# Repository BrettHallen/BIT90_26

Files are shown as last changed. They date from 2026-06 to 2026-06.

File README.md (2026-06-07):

# BIT90/26
An attempted recreation of the BIT90 computer released by Bit Corporation (普澤有限公司) in 1983 that is about [US$90,000 (AU$125,000) cheaper than a used one](https://web.archive.org/web/20260206154213/https://www.ebay.com/itm/127471879150):<br>
- Z80 CPU
- TMS9929A VDP
- 2KB RAM (one TC5517/4016 SRAM) expandable to 32KB (expansion cartridge)
- 16KB VRAM (eight 4116 DRAM)
- 24KB ROM (two 2364 + one 2764 or a variation) containing BASIC & Colecovision firmware (?)
- RF & composite video output
- two joystick ports
- Colecovision cartridge/tape compatible (2x15 pin)
- combination audio/video/tape port (DE9)
- expansion edge connector (2x30 pin)
- 5-pin DIN for power (±5V & +12V)

BIT90 original

Heavily relying on all the excellent information shared by [b3rendsh](https://github.com/b3rendsh) in their [BIT90 repository](https://github.com/b3rendsh/bit90).<br>

## [Part 1](/KiCad/BIT90_Original/) - Completed (enough)
The initial aim of the project is to recreate the original schematics in KiCad:<br>
- Sheet 6-1 (Processor): ✅ completed
- Sheet 6-2 (Video Control): ✅ completed
- Sheet 6-3 (Joystick, Audio, Tape): ✅ completed
- Sheet 6-4 (Keyboard): ✅ completed
- Sheet 6-5 (PAL Video Encoder): ❌ lost interest, using a Pico9918 so no point
- Sheet 6-6 (Expansion): ✅ completed
- Sheet 7-5 (PAL Video Encoder/32K): ❌ not needed for recreation
- 32K DRAM (4416x4): 🤔 pending, if I can get the base model working

The Video Encoder schematic isn't really relevant to my proposed re-design so haven't bothered completing them.<br>

Sheet 7-5 and the 32KB DRAM sheets appear to be for an updated system with 32KB of RAM?  This would be the ultimate aim, but let's see if we can get the initial 8KB system working.<br>

## Part 2 - Ongoing
The second part will be to try to create a modern replica as a single board computer.<br>

Ideally:
- integrated keyboard
- upgraded 8KB of RAM
- replace VDP9929A & 16KB DRAM with a [Pico9918](https://github.com/visrealm/pico9918)
- HDMI video output (thanks to the Pico9918)
- replace tri-voltage ±5VDC & 12VDC power requirement with a single 5VDC via USB or 2.1mm socket

The main hurdle would be sourcing the SN76489AN sound generator but I don't think this is ... currently (June 2026) ... too difficult. If you are wary of Chinese sellers, a reliable source of genuine parts is [Unicorn Electronics](https://unicornelectronics.com/IC/GENERATORS.html) in the US.  Grab yourself some EPROMs or exotic CPUs whilst you're there.<br>

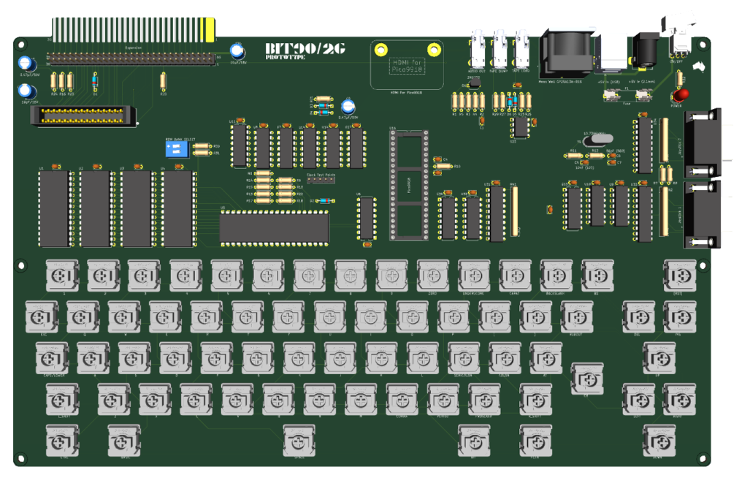
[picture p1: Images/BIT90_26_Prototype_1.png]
Prototype progress


## Keyboard
Recreation of the original keyboard layout.<br>
Designed with [Keyboard Layout Editor](https://www.keyboard-layout-editor.com/) which generates a JOSN file that can be used to generate a template for the key switches with [Plate & Case Builder](http://builder.swillkb.com).<br>

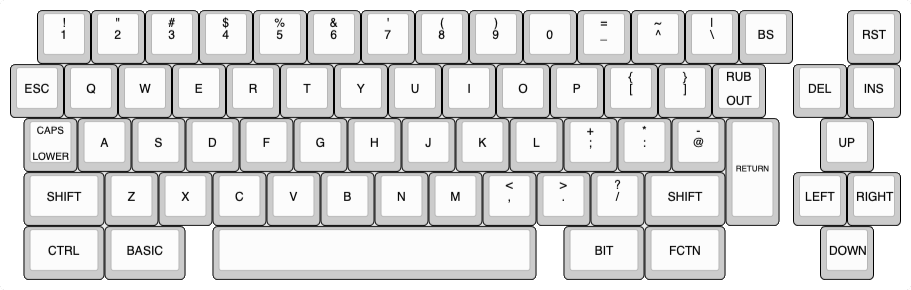
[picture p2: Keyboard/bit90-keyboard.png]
Keyboard layout


## ROMs
The original ROMs (BASIC v3.0) have been dumped and can be found [here](https://forums.atariage.com/topic/296435-bit-90-computer-roms-finally-dumped/).<br>

## BBC Basic
You can now also use a version of BBC Basic on the BIT90 thanks to [b3rendsh's](https://github.com/b3rendsh) work developing [BBX80](https://github.com/b3rendsh/bbx80).<br>

## Status
- 3/JUN/2026: Working on [Part 1](/KiCad/BIT90_Original/)
- 4/JUN/2026: Keyboard layout re-created & template generated
- 5/JUN/2026: Initial redesign [(schematic)](/KiCad/BIT90_26/) completed, error checking/fixing to follow
- 6/JUN/2026: PCB layout started

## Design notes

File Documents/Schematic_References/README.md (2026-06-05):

# Schematic References
Material I used as reference for creating the BIT90 schematics.  Reproduced here in case original links, Google drives, etc. disappear (that never happens, right?).<br>

## BIT90 System
Service manual schematics thanks to [H.J.Berends](https://github.com/b3rendsh/bit90) BIT90 repository.

## ColecoVision Schematic
Thanks to [Dan Boris](https://wiki.console5.com/wiki/Colecovision) on Console5 Wiki.

## ColecoVision KiCad Schematic
Thanks to [ChildOfCv](https://forums.atariage.com/topic/285656-new-colecovision-schematics/) user on AtariAge forums.

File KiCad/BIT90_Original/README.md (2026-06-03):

# BIT90 Original Schematics
Recreated from the [service manual schematics](https://github.com/b3rendsh/bit90/tree/main/docs) with errors corrected, or questioning comments when I couldn't figure it out.<br>

Planning to use these as a basis for a recreated machine - these are not meant to be used for a one-to-one recreation (i.e. not bothering assigning footprints or working on the PCB file) ... but do what you wish with them.<br>

Any errors are either slavishly copied from the original or misinterpreted by me.<br>

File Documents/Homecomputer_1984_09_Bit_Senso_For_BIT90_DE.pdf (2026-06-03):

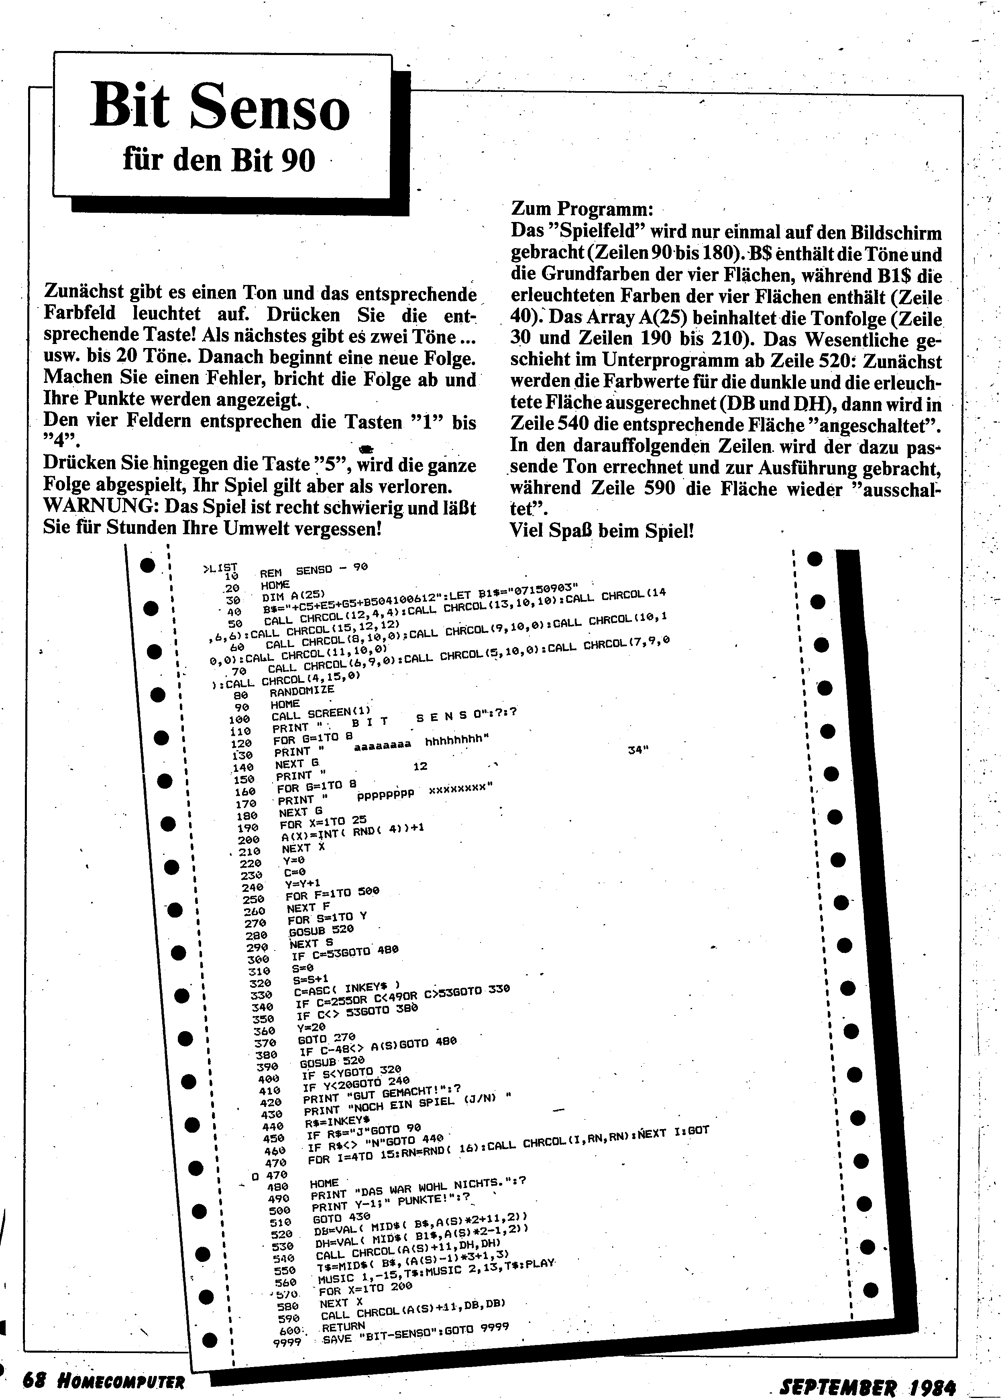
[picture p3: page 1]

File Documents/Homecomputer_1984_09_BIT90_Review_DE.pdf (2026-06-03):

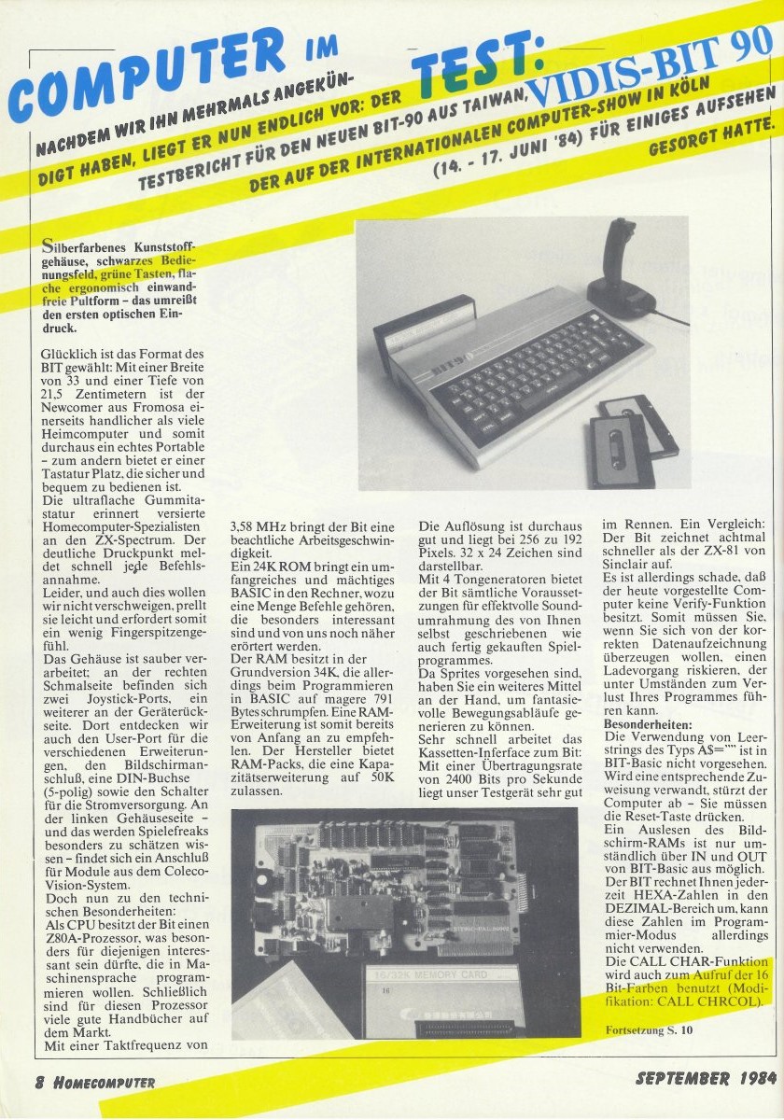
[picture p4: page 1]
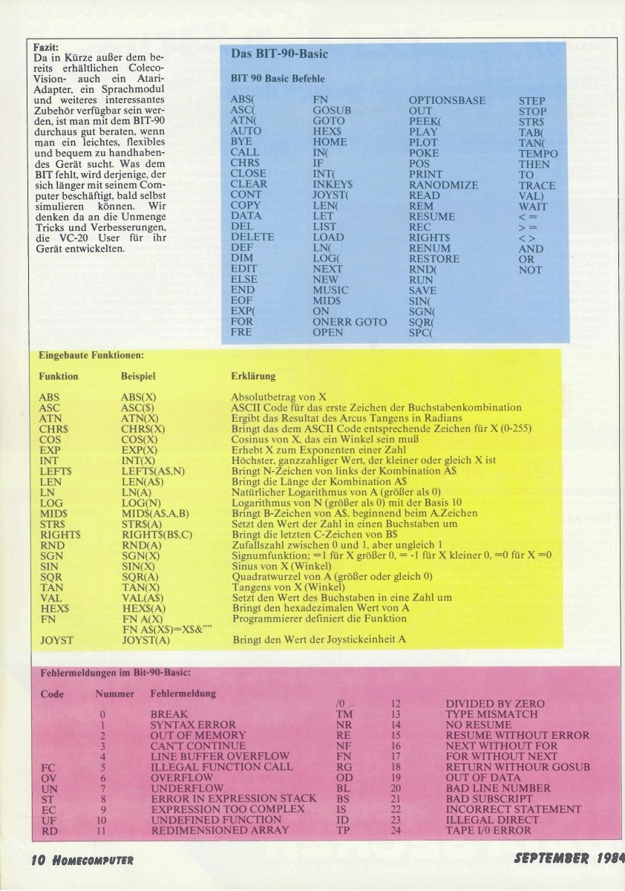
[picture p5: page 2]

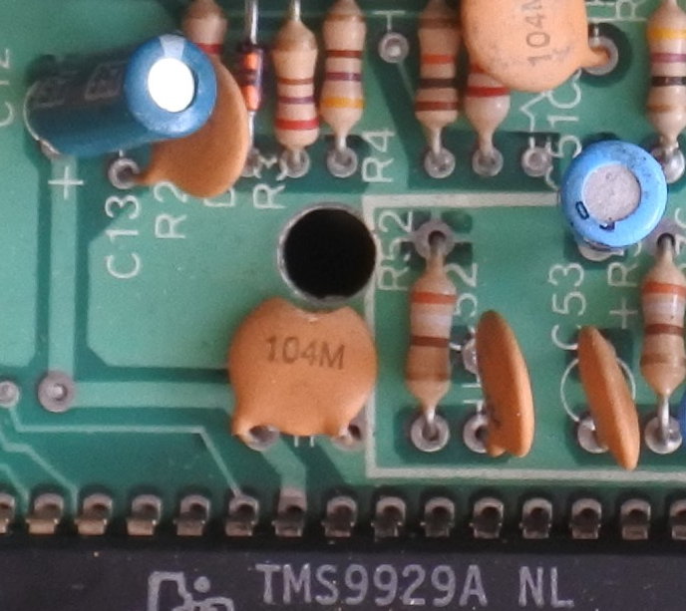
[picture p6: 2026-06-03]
Images/BIT90_motherboard_oopsie.jpg

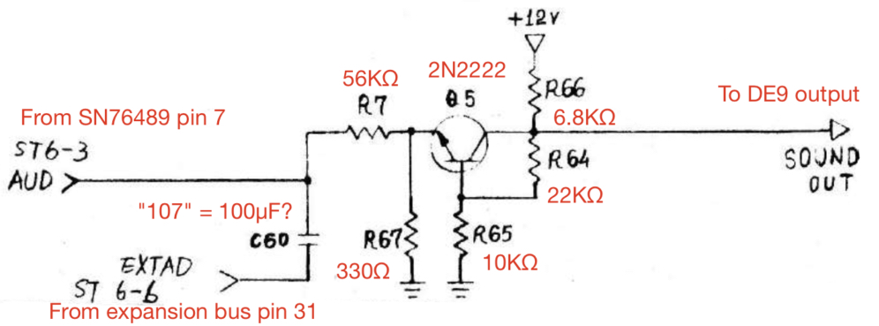
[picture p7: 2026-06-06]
KiCad/BIT90_Scraps/BIT90_sound_output.jpg

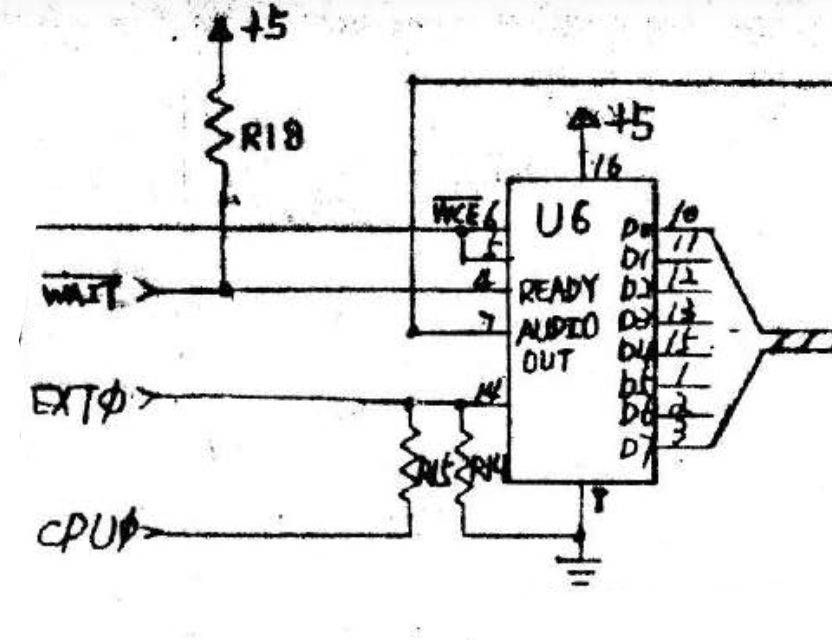
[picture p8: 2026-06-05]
KiCad/BIT90_Scraps/BIT90_Audio_Clocks.jpg

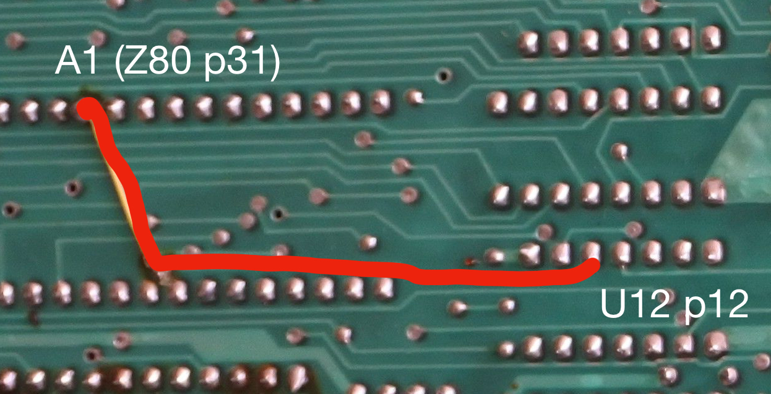
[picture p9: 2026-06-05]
KiCad/BIT90_Scraps/BIT90_scrap1.jpg

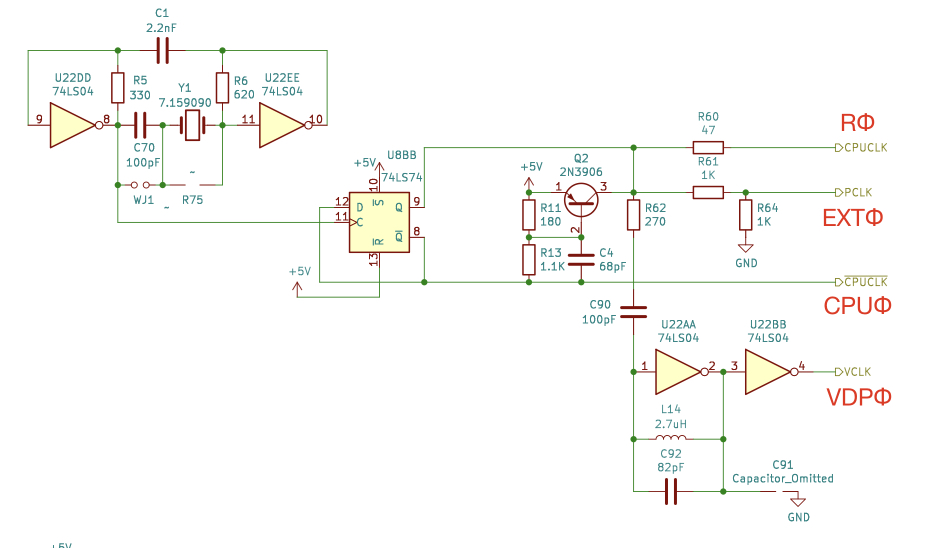
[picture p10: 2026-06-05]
KiCad/BIT90_Scraps/CV_Clocks.jpg

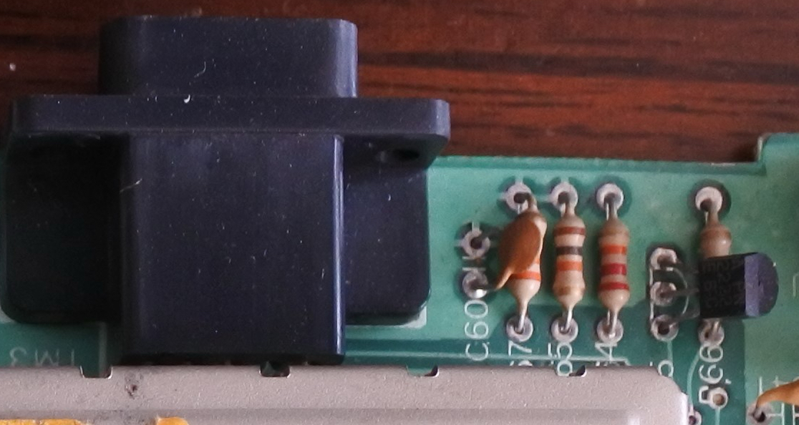
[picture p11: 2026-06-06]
KiCad/BIT90_Scraps/BIT90_sound_output_motherboard.jpg

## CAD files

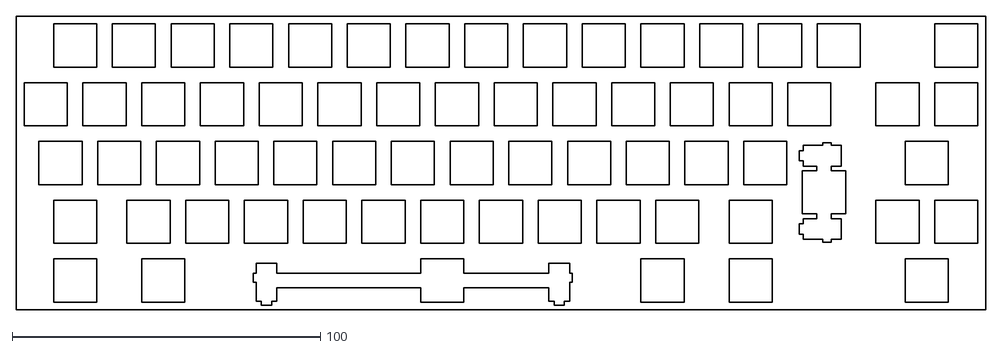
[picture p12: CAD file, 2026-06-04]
Keyboard/bit90-keyboard_switch_template.dxf
314.3 x 95.2

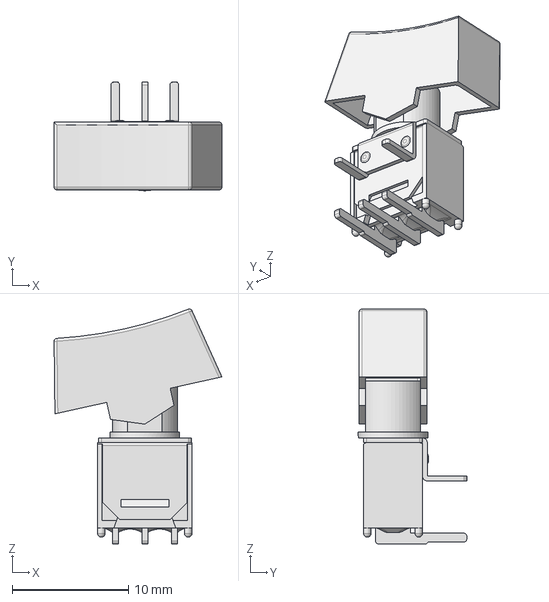
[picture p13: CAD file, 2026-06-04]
KiCad/Symbols/400MSP1R6BLKM6QE/400MSP1R6BLKM6QE.step
14.5 x 9.35 x 20.2 mm

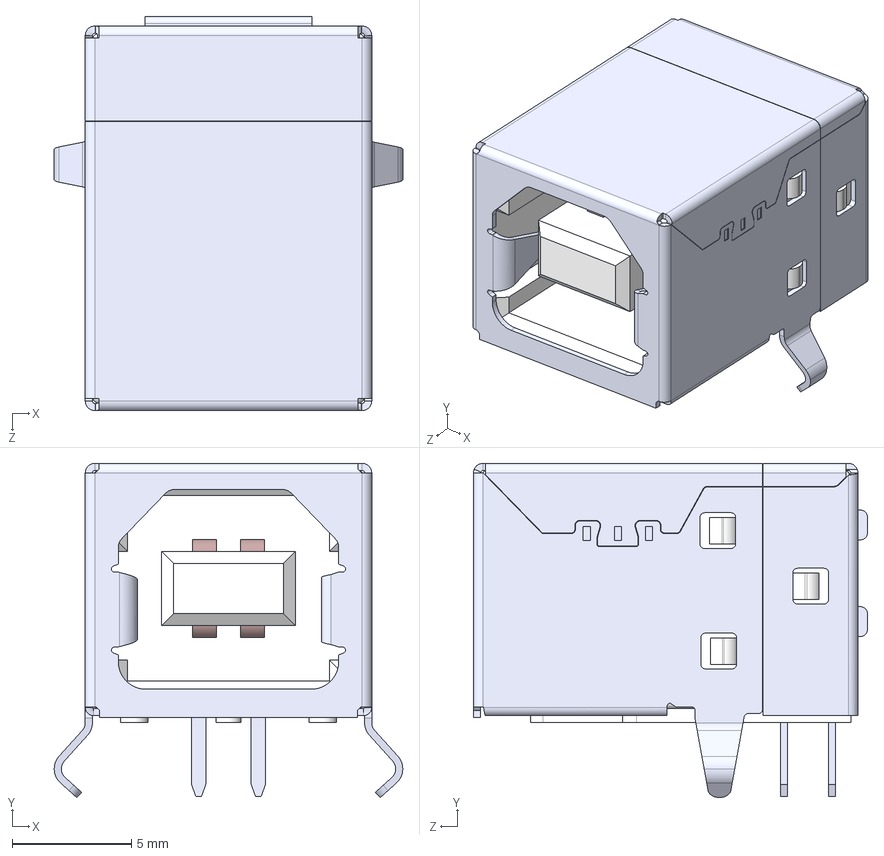
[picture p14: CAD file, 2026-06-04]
KiCad/Symbols/AU_Y1007/AU-Y1007.step
14.6 x 14.0 x 16.5 mm

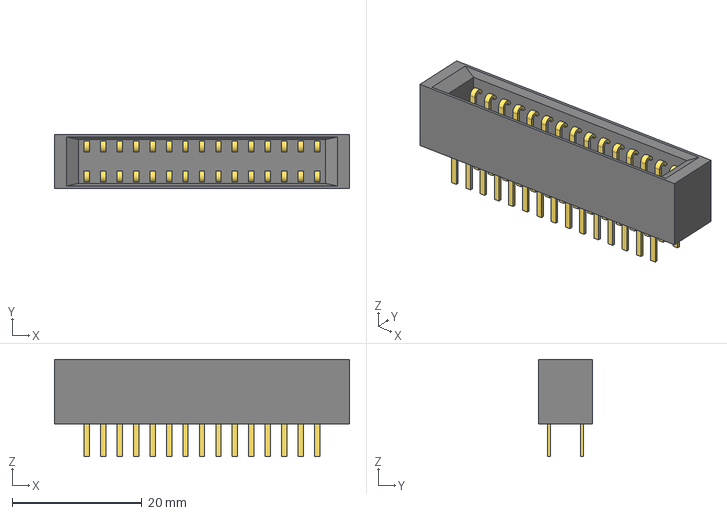
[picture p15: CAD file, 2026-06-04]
KiCad/Symbols/EBC15DRXN/CONN30_2x15_DRXN_SUL.step
45.5 x 8.38 x 15.0 mm

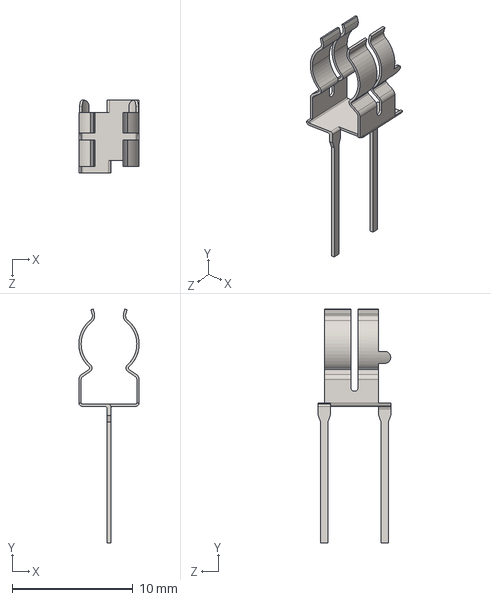
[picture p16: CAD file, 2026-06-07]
KiCad/Symbols/51900001009.stp
5.00 x 19.4 x 6.00 mm

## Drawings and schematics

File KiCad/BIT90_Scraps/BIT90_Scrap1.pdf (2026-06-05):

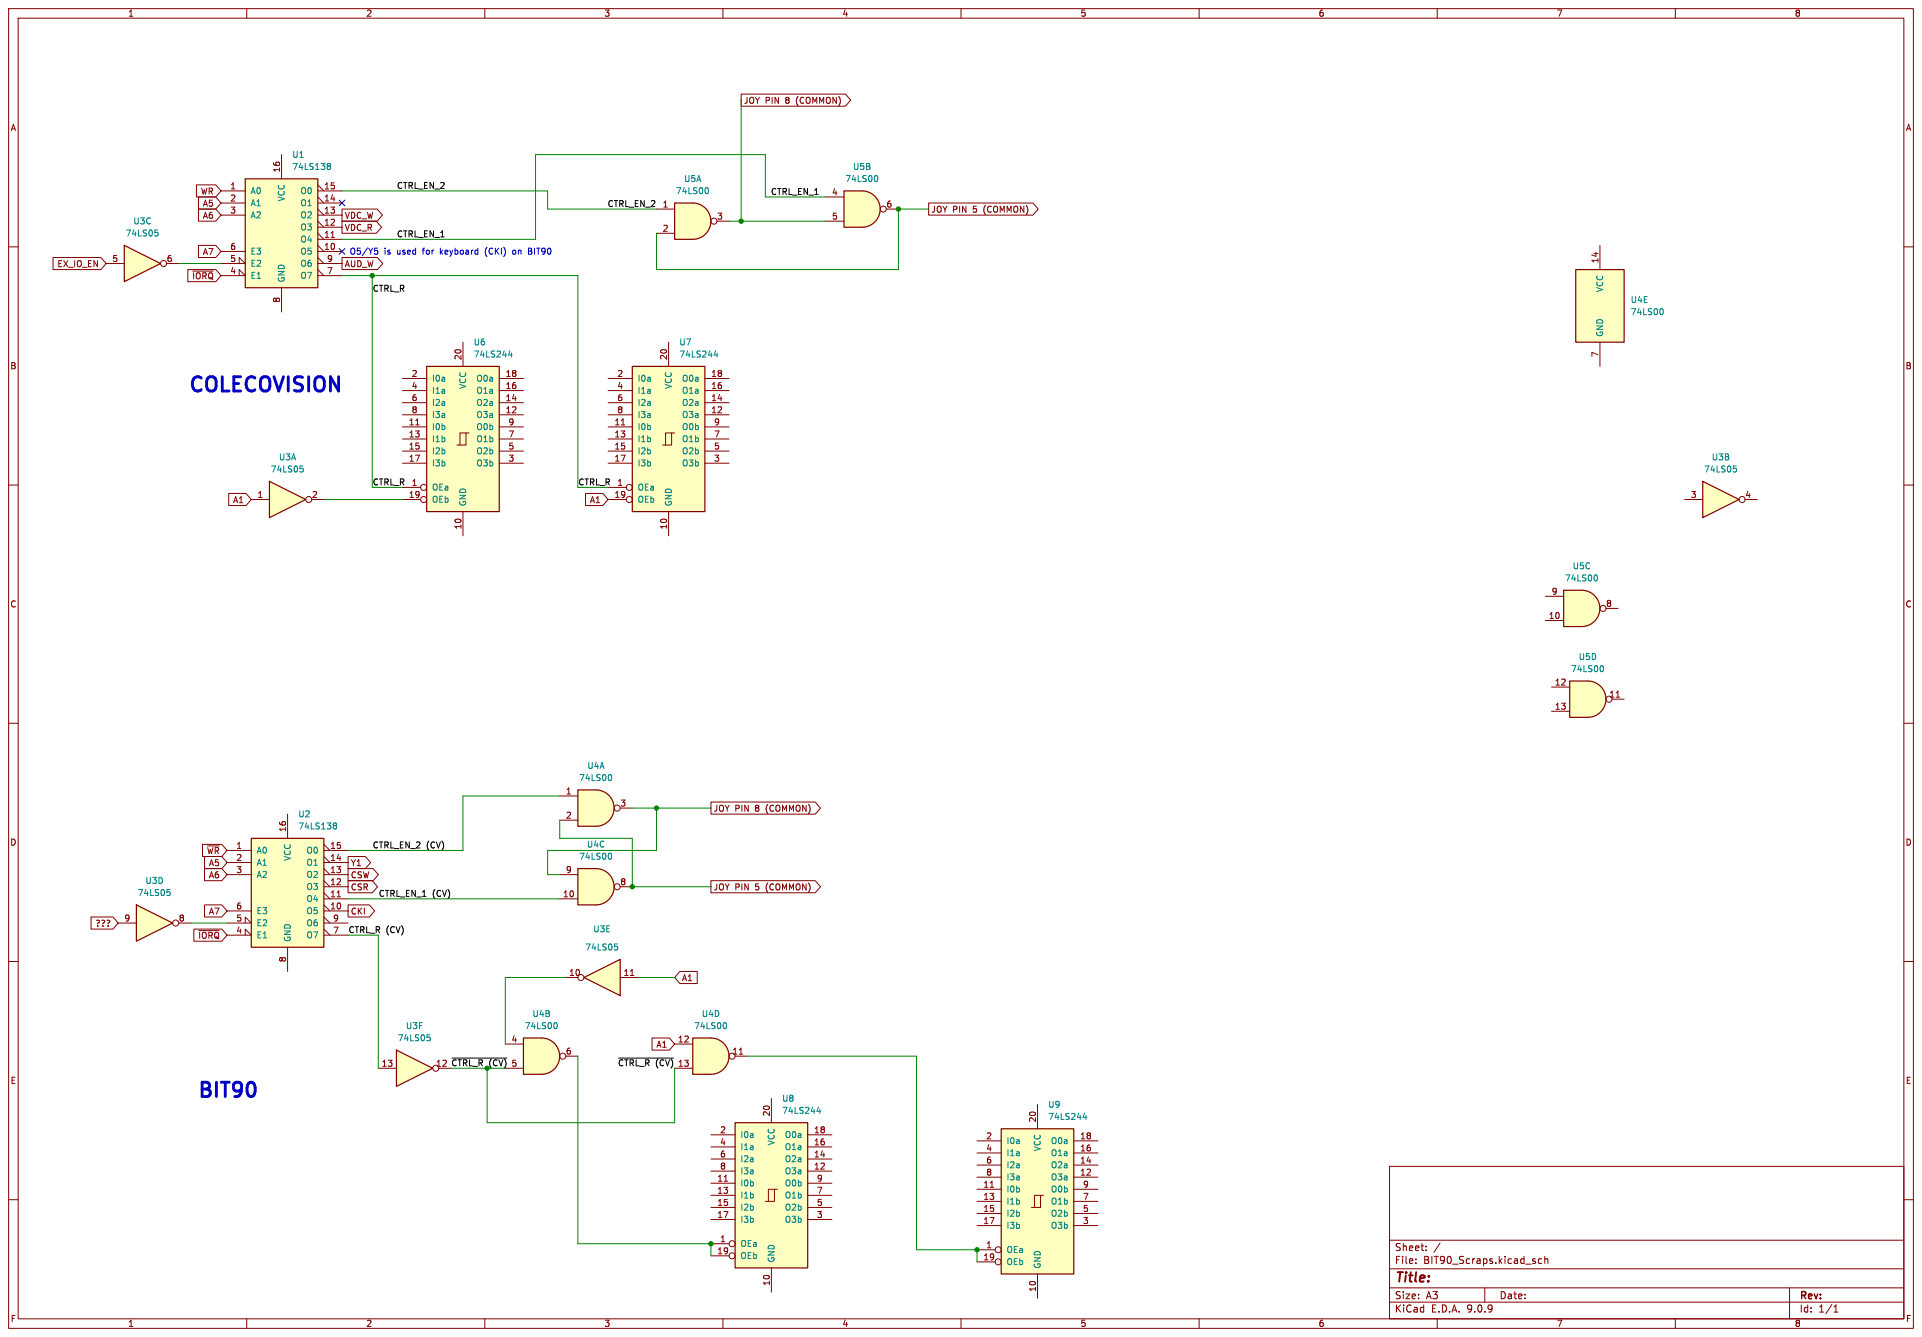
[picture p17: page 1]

O5/Y5 is used for keyboard (CKI) on BIT90 BIT90

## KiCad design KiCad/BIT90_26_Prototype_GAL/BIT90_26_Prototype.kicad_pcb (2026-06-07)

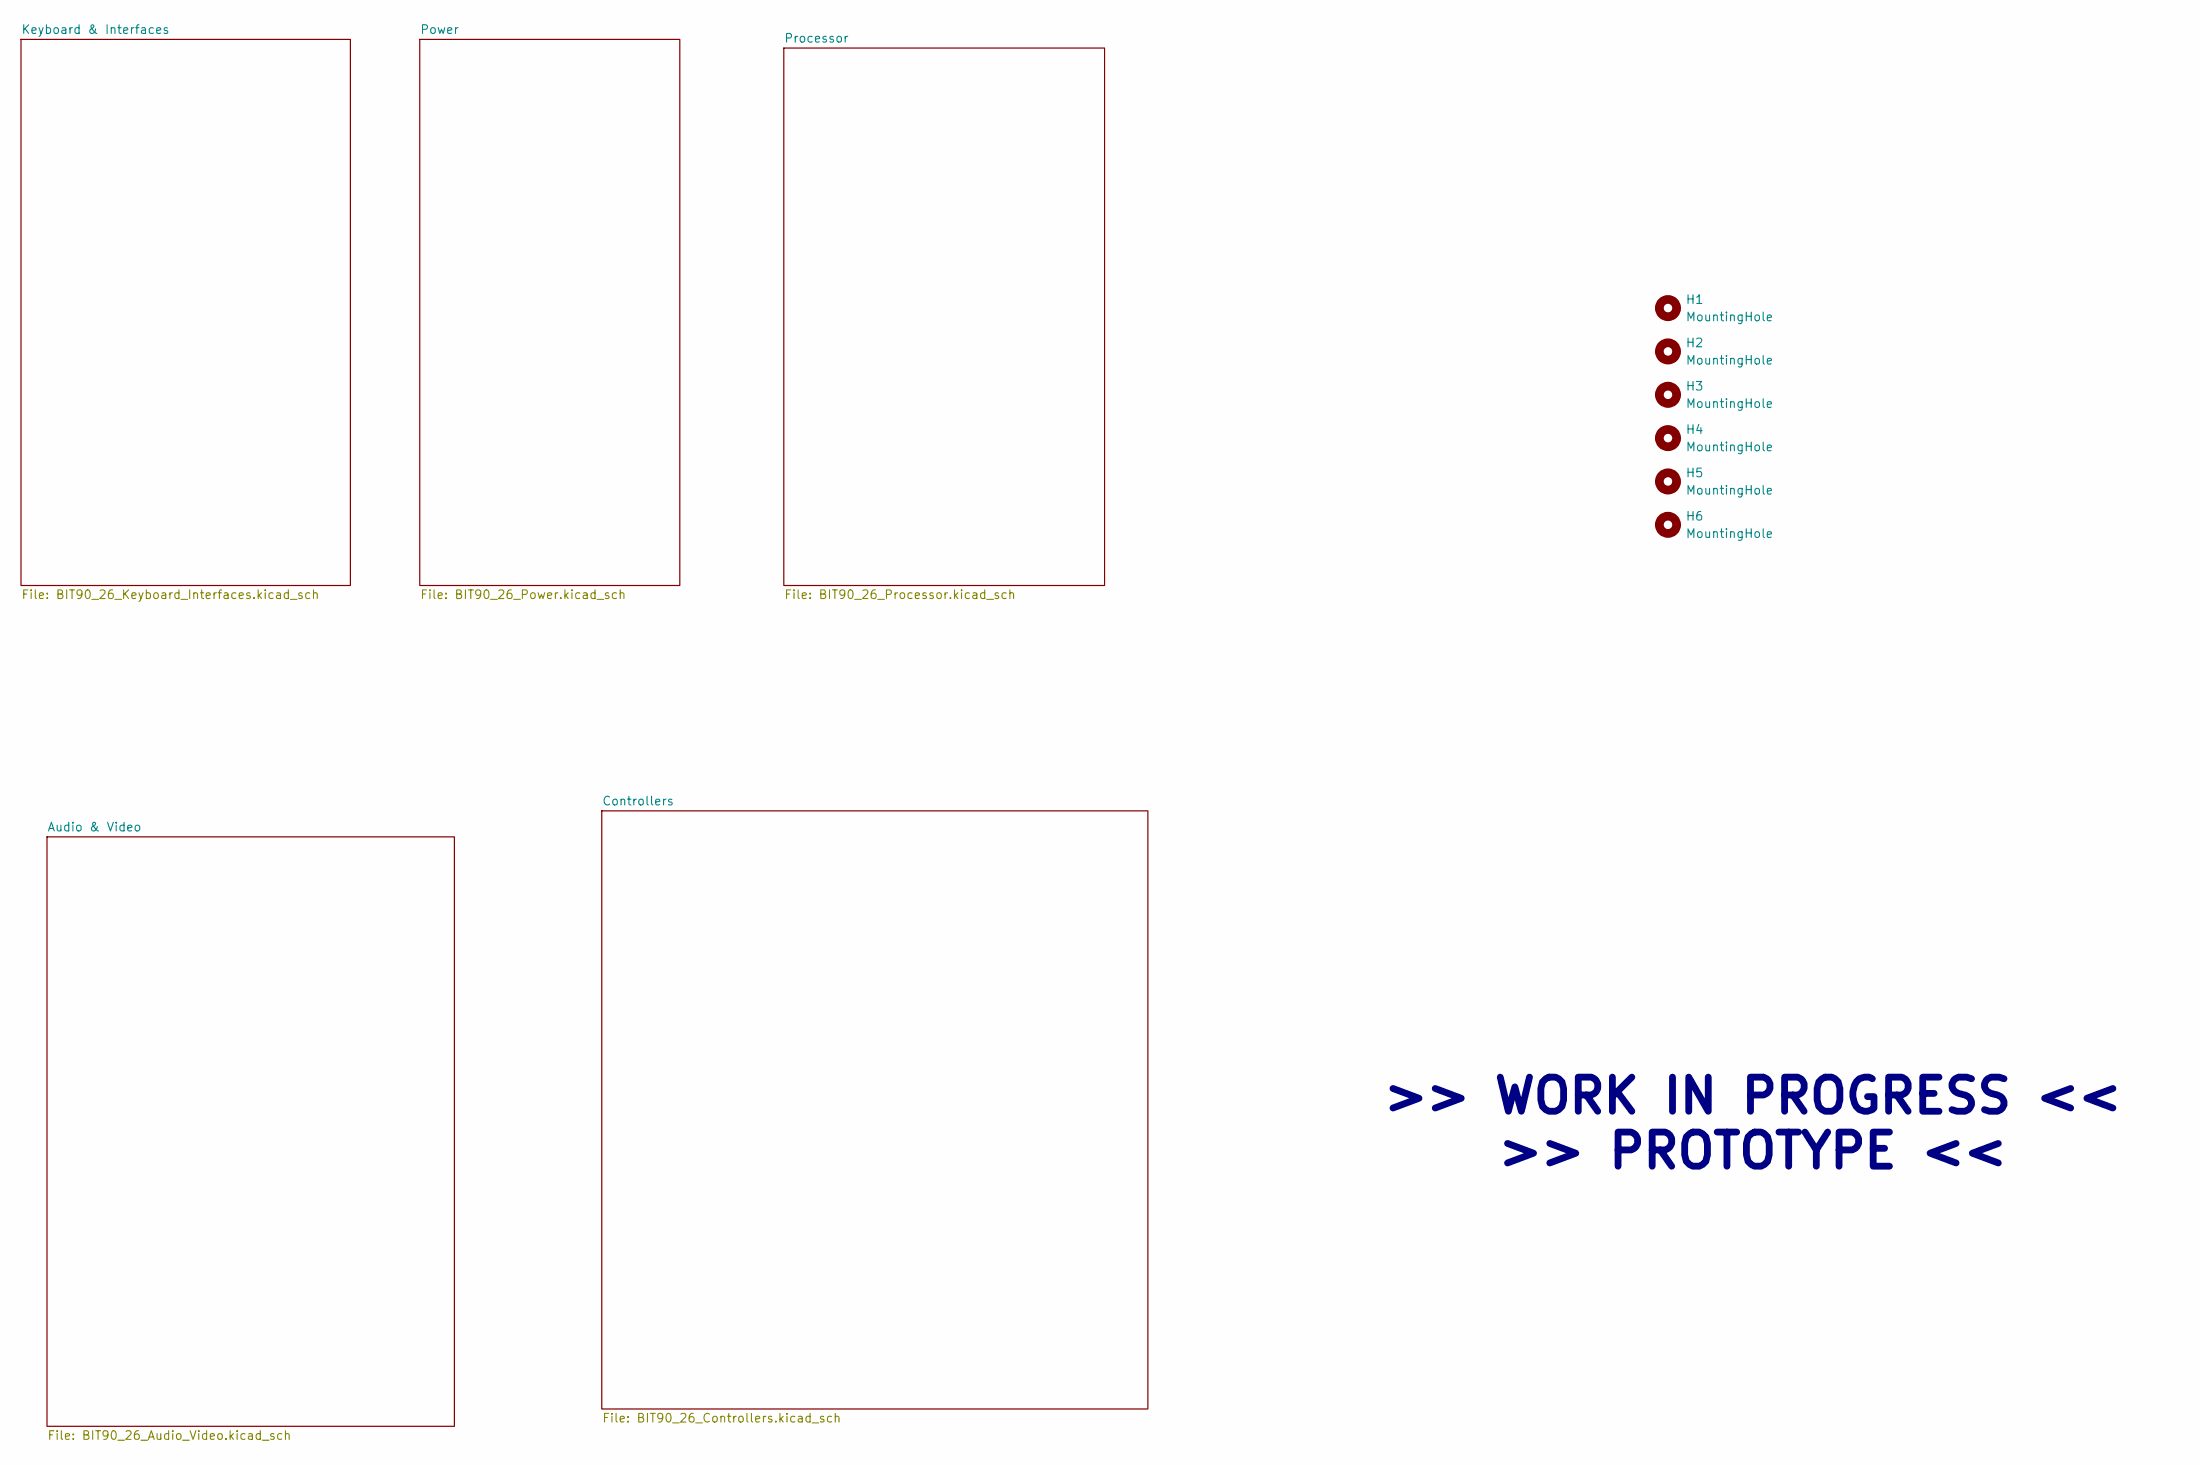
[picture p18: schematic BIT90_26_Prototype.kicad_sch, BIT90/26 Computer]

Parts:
H1, H2, H3, H4, H5, H6: MountingHole; MountingHole_3.2mm_M3

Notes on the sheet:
>> WORK IN PROGRESS << >> PROTOTYPE <<

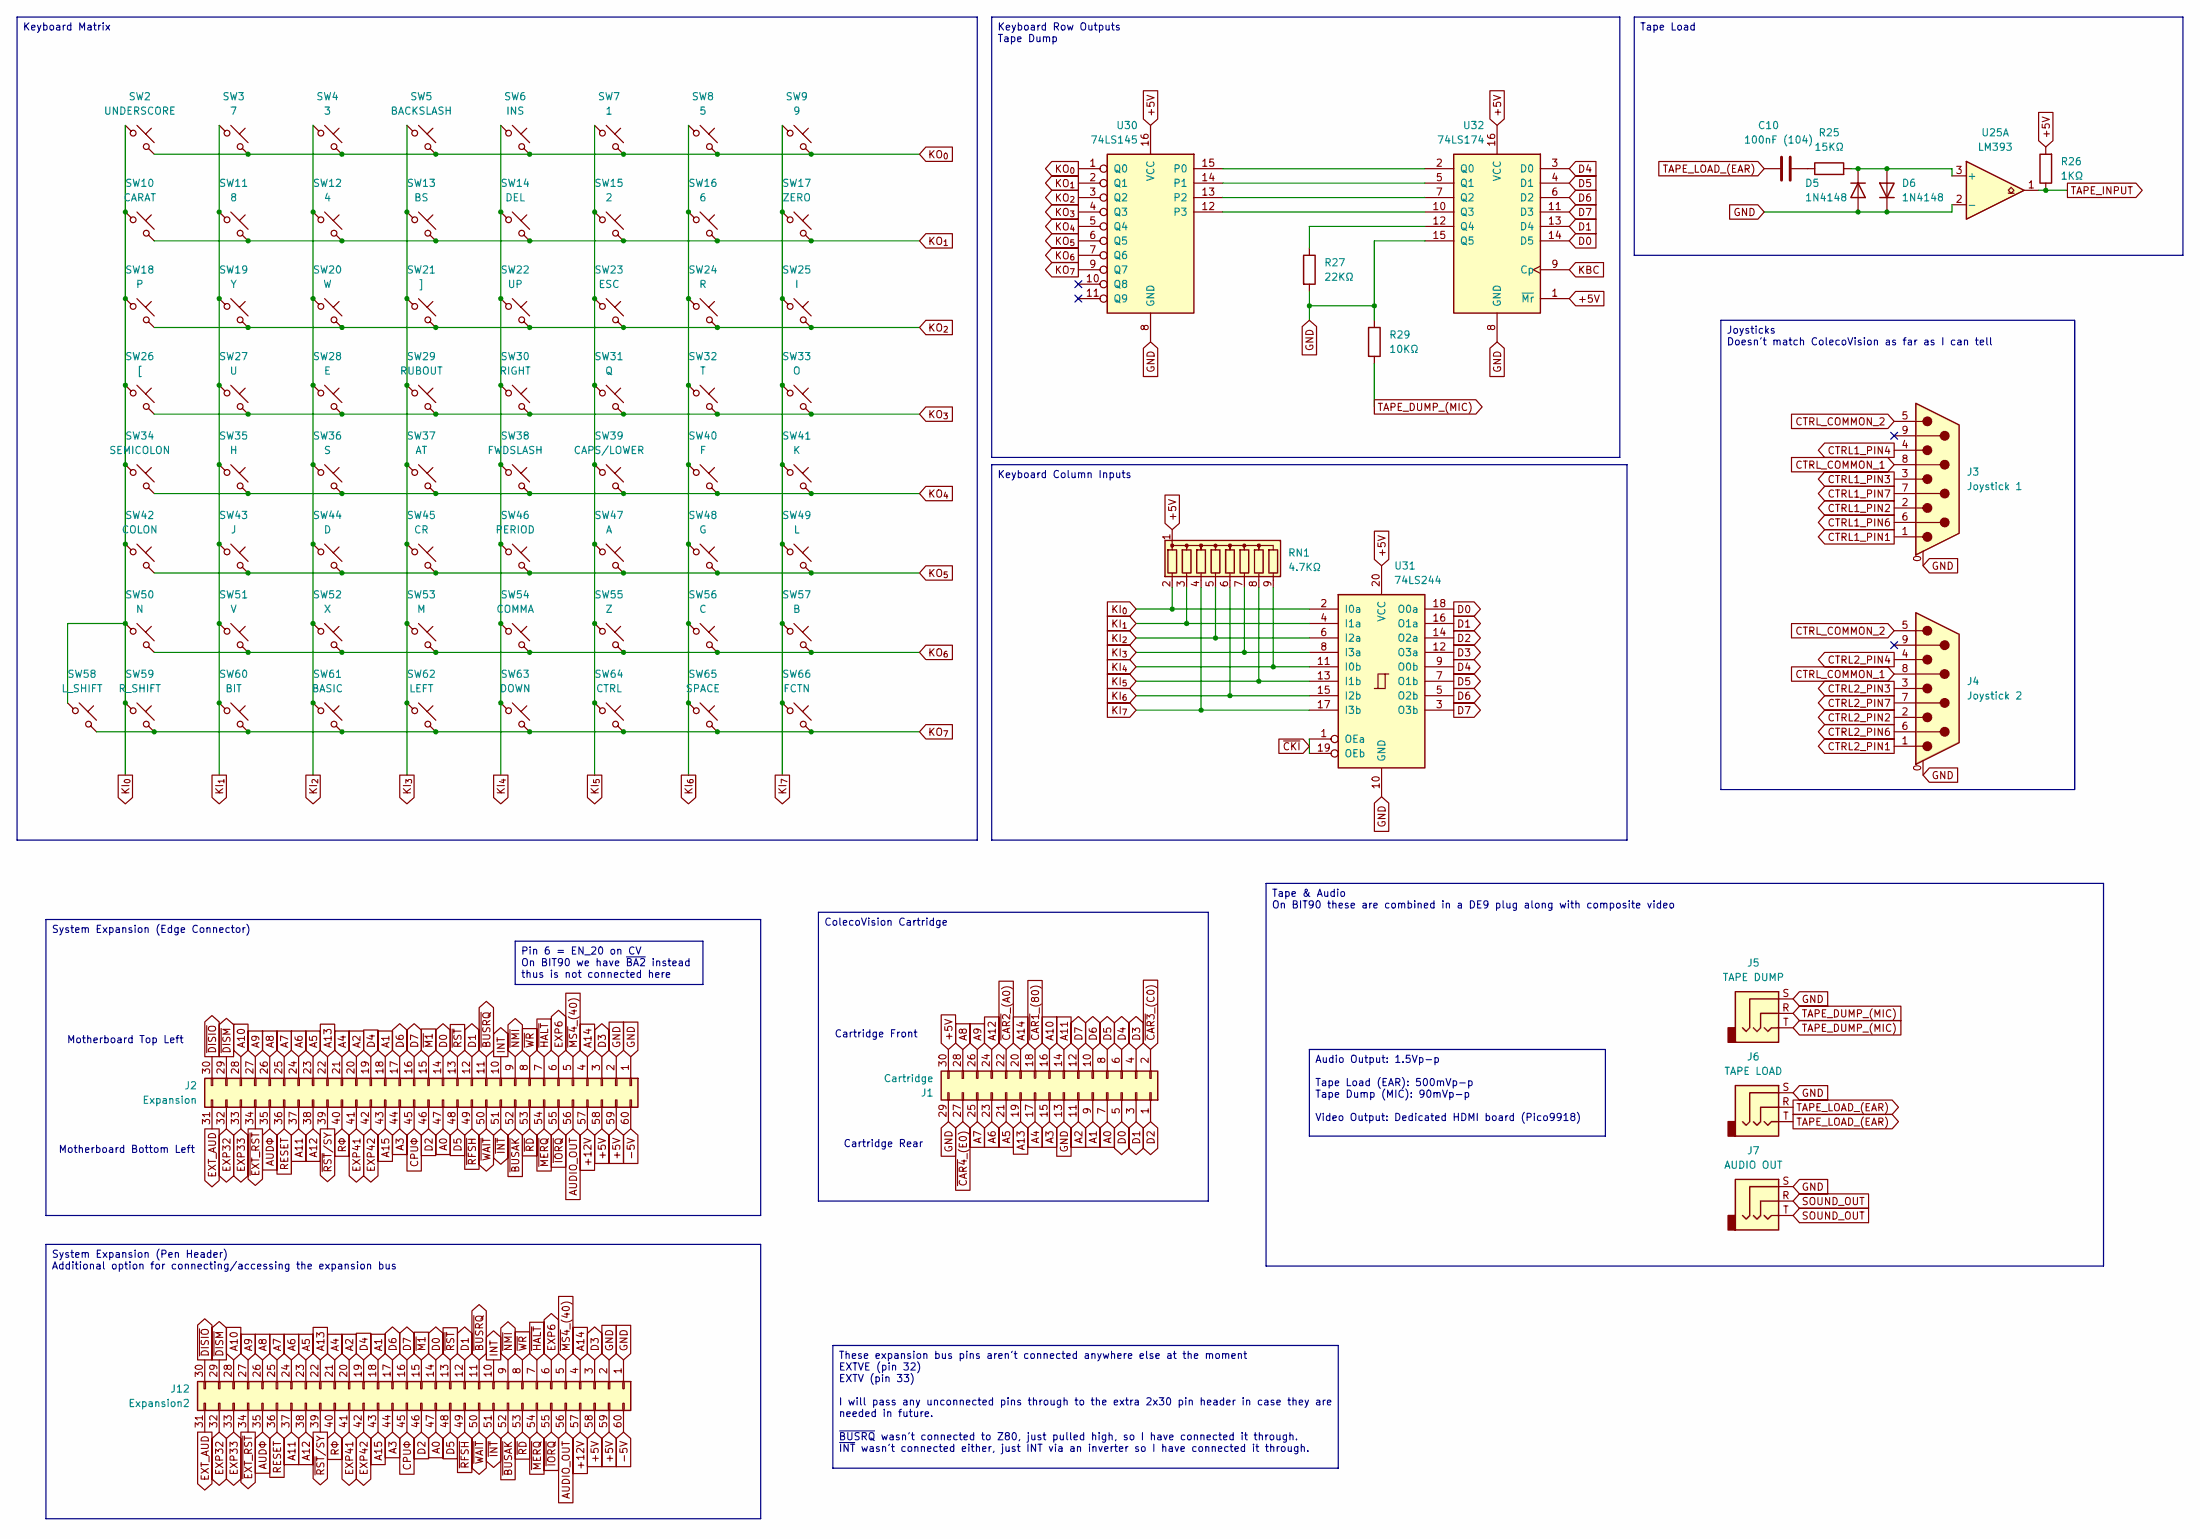
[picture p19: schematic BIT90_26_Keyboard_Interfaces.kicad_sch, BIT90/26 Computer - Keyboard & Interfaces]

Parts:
C10: 100nF (104); C_Disc_D3.4mm_W2.1mm_P2.50mm
D5, D6: 1N4148; D_DO-35_SOD27_P7.62mm_Horizontal
J1: Cartridge; CONN30_2x15_DRXN_SUL
J2: Expansion; BIT90 Expansion
J3: Joystick 1; DSUB-9_Pins_Horizontal_P2.77x2.84mm_EdgePinOffset7.70mm_Hou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
J4: Joystick 2; DSUB-9_Pins_Horizontal_P2.77x2.84mm_EdgePinOffset7.70mm_Hou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
J5: TAPE DUMP; SJ335083ATR
J6: TAPE LOAD; SJ335083ATR
J7: AUDIO OUT; SJ335083ATR
J12: Expansion2; PinHeader_2x30_P2.54mm_Vertical
R25: 15KΩ; R_Axial_DIN0207_L6.3mm_D2.5mm_P7.62mm_Horizontal
R26: 1KΩ; R_Axial_DIN0207_L6.3mm_D2.5mm_P7.62mm_Horizontal
R27: 22KΩ; R_Axial_DIN0207_L6.3mm_D2.5mm_P7.62mm_Horizontal
R29: 10KΩ; R_Axial_DIN0207_L6.3mm_D2.5mm_P7.62mm_Horizontal
RN1: 4.7KΩ; R_Array_SIP9
SW2: UNDERSCORE; SW_Gateron_LowProfile_THT
SW3: 7; SW_Gateron_LowProfile_THT
SW4: 3; SW_Gateron_LowProfile_THT
SW5: BACKSLASH; SW_Gateron_LowProfile_THT
SW6: INS; SW_Gateron_LowProfile_THT
SW7: 1; SW_Gateron_LowProfile_THT
SW8: 5; SW_Gateron_LowProfile_THT
SW9: 9; SW_Gateron_LowProfile_THT
SW10: CARAT; SW_Gateron_LowProfile_THT
SW11: 8; SW_Gateron_LowProfile_THT
SW12: 4; SW_Gateron_LowProfile_THT
SW13: BS; SW_Gateron_LowProfile_THT
SW14: DEL; SW_Gateron_LowProfile_THT
SW15: 2; SW_Gateron_LowProfile_THT
SW16: 6; SW_Gateron_LowProfile_THT
SW17: ZERO; SW_Gateron_LowProfile_THT
SW18: P; SW_Gateron_LowProfile_THT
SW19: Y; SW_Gateron_LowProfile_THT
SW20: W; SW_Gateron_LowProfile_THT
SW21: ]; SW_Gateron_LowProfile_THT
SW22: UP; SW_Gateron_LowProfile_THT
SW23: ESC; SW_Gateron_LowProfile_THT
SW24: R; SW_Gateron_LowProfile_THT
SW25: I; SW_Gateron_LowProfile_THT
SW26: [; SW_Gateron_LowProfile_THT
SW27: U; SW_Gateron_LowProfile_THT
SW28: E; SW_Gateron_LowProfile_THT
SW29: RUBOUT; SW_Gateron_LowProfile_THT
SW30: RIGHT; SW_Gateron_LowProfile_THT
SW31: Q; SW_Gateron_LowProfile_THT
SW32: T; SW_Gateron_LowProfile_THT
SW33: O; SW_Gateron_LowProfile_THT
SW34: SEMICOLON; SW_Gateron_LowProfile_THT
SW35: H; SW_Gateron_LowProfile_THT
SW36: S; SW_Gateron_LowProfile_THT
SW37: AT; SW_Gateron_LowProfile_THT
SW38: FWDSLASH; SW_Gateron_LowProfile_THT
SW39: CAPS/LOWER; SW_Gateron_LowProfile_THT
SW40: F; SW_Gateron_LowProfile_THT
SW41: K; SW_Gateron_LowProfile_THT
SW42: COLON; SW_Gateron_LowProfile_THT
SW43: J; SW_Gateron_LowProfile_THT
SW44: D; SW_Gateron_LowProfile_THT
SW45: CR; SW_Gateron_LowProfile_THT
SW46: PERIOD; SW_Gateron_LowProfile_THT
SW47: A; SW_Gateron_LowProfile_THT
SW48: G; SW_Gateron_LowProfile_THT
SW49: L; SW_Gateron_LowProfile_THT
SW50: N; SW_Gateron_LowProfile_THT
SW51: V; SW_Gateron_LowProfile_THT
SW52: X; SW_Gateron_LowProfile_THT
SW53: M; SW_Gateron_LowProfile_THT
SW54: COMMA; SW_Gateron_LowProfile_THT
SW55: Z; SW_Gateron_LowProfile_THT
SW56: C; SW_Gateron_LowProfile_THT
SW57: B; SW_Gateron_LowProfile_THT
SW58: L_SHIFT; SW_Gateron_LowProfile_THT
SW59: R_SHIFT; SW_Gateron_LowProfile_THT
SW60: BIT; SW_Gateron_LowProfile_THT
SW61: BASIC; SW_Gateron_LowProfile_THT
SW62: LEFT; SW_Gateron_LowProfile_THT
SW63: DOWN; SW_Gateron_LowProfile_THT
SW64: CTRL; SW_Gateron_LowProfile_THT
SW65: SPACE; SW_Gateron_LowProfile_THT
SW66: FCTN; SW_Gateron_LowProfile_THT
U25: LM393; DIP-8_W7.62mm
U30: 74LS145; DIP-16_W7.62mm
U31: 74LS244; DIP-20_W7.62mm
U32: 74LS174; DIP-16_W7.62mm

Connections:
+5V: J1.30, J2.58, J2.59, J12.58, J12.59, R26.2, RN1.1 (common), U30.16 (VCC), U31.20 (VCC), U32.1 (~Mr), U32.16 (VCC); also elsewhere on the board
+12V: J2.57, J12.57; also elsewhere on the board
-5V: J2.60, J12.60; also elsewhere on the board
A0: J1.7, J2.47, J12.47; also elsewhere on the board
A1: J1.9, J2.18, J12.18; also elsewhere on the board
A2: J1.11, J2.20, J12.20; also elsewhere on the board
A3: J1.15, J2.44, J12.44; also elsewhere on the board
A4: J1.17, J2.21, J12.21; also elsewhere on the board
A5: J1.21, J2.23, J12.23; also elsewhere on the board
A6: J1.23, J2.24, J12.24; also elsewhere on the board
A7: J1.25, J2.25, J12.25; also elsewhere on the board
A8: J1.28, J2.26, J12.26; also elsewhere on the board
A9: J1.26, J2.27, J12.27; also elsewhere on the board
A10: J1.16, J2.28, J12.28; also elsewhere on the board
A11: J1.14, J2.37, J12.37; also elsewhere on the board
A12: J1.24, J2.38, J12.38; also elsewhere on the board
A13: J1.19, J2.22, J12.22; also elsewhere on the board
A14: J1.20, J2.4, J12.4; also elsewhere on the board
A15: J2.43, J12.43; also elsewhere on the board
AUDIO_OUT: J2.56, J12.56; also elsewhere on the board
AUDΦ: J2.35, J12.35; also elsewhere on the board
CPUΦ: J2.45, J12.45; also elsewhere on the board
CTRL1_PIN1: J3.1; also elsewhere on the board
CTRL1_PIN2: J3.2; also elsewhere on the board
CTRL1_PIN3: J3.3; also elsewhere on the board
CTRL1_PIN4: J3.4; also elsewhere on the board
CTRL1_PIN6: J3.6; also elsewhere on the board
CTRL1_PIN7: J3.7; also elsewhere on the board
CTRL2_PIN1: J4.1; also elsewhere on the board
CTRL2_PIN2: J4.2; also elsewhere on the board
CTRL2_PIN3: J4.3; also elsewhere on the board
CTRL2_PIN4: J4.4; also elsewhere on the board
CTRL2_PIN6: J4.6; also elsewhere on the board
CTRL2_PIN7: J4.7; also elsewhere on the board
CTRL_COMMON_1: J3.8, J4.8; also elsewhere on the board
CTRL_COMMON_2: J3.5, J4.5; also elsewhere on the board
D0: J1.5, J2.14, J12.14, U31.18 (O0a), U32.14 (D5); also elsewhere on the board
D1: J1.3, J2.12, J12.12, U31.16 (O1a), U32.13 (D4); also elsewhere on the board
D2: J1.1, J2.46, J12.46, U31.14 (O2a); also elsewhere on the board
D3: J1.4, J2.3, J12.3, U31.12 (O3a); also elsewhere on the board
D4: J1.6, J2.19, J12.19, U31.9 (O0b), U32.3 (D0); also elsewhere on the board
D5: J1.8, J2.48, J12.48, U31.7 (O1b), U32.4 (D1); also elsewhere on the board
D6: J1.10, J2.17, J12.17, U31.5 (O2b), U32.6 (D2); also elsewhere on the board
D7: J1.12, J2.16, J12.16, U31.3 (O3b), U32.11 (D3); also elsewhere on the board
EXP6: J2.6, J12.6
EXP32: J2.32, J12.32
EXP33: J2.33, J12.33
EXP41: J2.41, J12.41
EXP42: J2.42, J12.42
EXT_AUD: J2.31, J12.31; also elsewhere on the board
GND: D5.2 (A), D6.1 (K), J1.13, J1.29, J2.1, J2.2, J3.0 (SH), J4.0 (SH), J5.S, J6.S, J7.S, J12.1, J12.2, R27.2, R29.1, U25.2 (-), U30.8 (GND), U31.10 (GND), U32.8 (GND), U32.15 (Q5); also elsewhere on the board
INT: J2.10, J12.10; also elsewhere on the board
KBC: U32.9 (Cp); also elsewhere on the board
KI_{0}: RN1.2 (R1), SW2.1, SW10.1, SW18.1, SW26.1, SW34.1, SW42.1, SW50.1, SW58.1, SW59.1, U31.2 (I0a)
KI_{1}: RN1.3 (R2), SW3.1, SW11.1, SW19.1, SW27.1, SW35.1, SW43.1, SW51.1, SW60.1, U31.4 (I1a)
KI_{2}: RN1.5 (R4), SW4.1, SW12.1, SW20.1, SW28.1, SW36.1, SW44.1, SW52.1, SW61.1, U31.6 (I2a)
KI_{3}: RN1.7 (R6), SW5.1, SW13.1, SW21.1, SW29.1, SW37.1, SW45.1, SW53.1, SW62.1, U31.8 (I3a)
KI_{4}: RN1.9 (R8), SW6.1, SW14.1, SW22.1, SW30.1, SW38.1, SW46.1, SW54.1, SW63.1, U31.11 (I0b)
KI_{5}: RN1.8 (R7), SW7.1, SW15.1, SW23.1, SW31.1, SW39.1, SW47.1, SW55.1, SW64.1, U31.13 (I1b)
KI_{6}: RN1.6 (R5), SW8.1, SW16.1, SW24.1, SW32.1, SW40.1, SW48.1, SW56.1, SW65.1, U31.15 (I2b)
KI_{7}: RN1.4 (R3), SW9.1, SW17.1, SW25.1, SW33.1, SW41.1, SW49.1, SW57.1, SW66.1, U31.17 (I3b)
KO_{0}: SW2.2, SW3.2, SW4.2, SW5.2, SW6.2, SW7.2, SW8.2, SW9.2, U30.1 (Q0)
KO_{1}: SW10.2, SW11.2, SW12.2, SW13.2, SW14.2, SW15.2, SW16.2, SW17.2, U30.2 (Q1)
KO_{2}: SW18.2, SW19.2, SW20.2, SW21.2, SW22.2, SW23.2, SW24.2, SW25.2, U30.3 (Q2)
KO_{3}: SW26.2, SW27.2, SW28.2, SW29.2, SW30.2, SW31.2, SW32.2, SW33.2, U30.4 (Q3)
KO_{4}: SW34.2, SW35.2, SW36.2, SW37.2, SW38.2, SW39.2, SW40.2, SW41.2, U30.5 (Q4)
KO_{5}: SW42.2, SW43.2, SW44.2, SW45.2, SW46.2, SW47.2, SW48.2, SW49.2, U30.6 (Q5)
KO_{6}: SW50.2, SW51.2, SW52.2, SW53.2, SW54.2, SW55.2, SW56.2, SW57.2, U30.7 (Q6)
KO_{7}: SW58.2, SW59.2, SW60.2, SW61.2, SW62.2, SW63.2, SW64.2, SW65.2, SW66.2, U30.9 (Q7)
unnamed: C10.2, R25.1
unnamed: D5.1 (K), D6.2 (A), R25.2, U25.3 (+)
unnamed: U30.15 (P0), U32.2 (Q0)
unnamed: U30.14 (P1), U32.5 (Q1)
unnamed: U30.13 (P2), U32.7 (Q2)
unnamed: U30.12 (P3), U32.10 (Q3)
unnamed: R27.1, U32.12 (Q4)
RESET: J2.36, J12.36; also elsewhere on the board
RΦ: J2.40, J12.40; also elsewhere on the board
SOUND_OUT: J7.R, J7.T; also elsewhere on the board
TAPE_DUMP_(MIC): J5.R, J5.T, R29.2
TAPE_INPUT: R26.1, U25.1; also elsewhere on the board
TAPE_LOAD_(EAR): C10.1, J6.R, J6.T
~BUSAK: J2.52, J12.52; also elsewhere on the board
~BUSRQ: J2.11, J12.11; also elsewhere on the board
~CAR1_(80): J1.18; also elsewhere on the board
~CAR2_(A0): J1.22; also elsewhere on the board
~CAR3_(C0): J1.2; also elsewhere on the board
~CAR4_(E0): J1.27; also elsewhere on the board
~CKI: U31.1 (OEa), U31.19 (OEb); also elsewhere on the board
~DISIO: J2.30, J12.30; also elsewhere on the board
~DISM: J2.29, J12.29; also elsewhere on the board
~EXT_RST: J2.34, J12.34; also elsewhere on the board
~HALT: J2.7, J12.7; also elsewhere on the board
~INT: J2.51, J12.51; also elsewhere on the board
~IORQ: J2.55, J12.55; also elsewhere on the board
~M1: J2.15, J12.15; also elsewhere on the board
~MERQ: J2.54, J12.54; also elsewhere on the board
~MS4_(40): J2.5, J12.5; also elsewhere on the board
~NMI: J2.9, J12.9; also elsewhere on the board
~RD: J2.53, J12.53; also elsewhere on the board
~RFSH: J2.49, J12.49; also elsewhere on the board
~RST: J2.13, J12.13; also elsewhere on the board
~RST/SY: J2.39, J12.39; also elsewhere on the board
~WAIT: J2.50, J12.50; also elsewhere on the board
~WR: J2.8, J12.8; also elsewhere on the board

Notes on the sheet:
Motherboard Top Left
Motherboard Bottom Left
Cartridge Rear
Cartridge Front
Joysticks Doesn't match ColecoVision as far as I can tell
Keyboard Row Outputs Tape Dump
ColecoVision Cartridge
Tape Load
Pin 6 = EN_20 on CV On BIT90 we have ~{BA2} instead thus is not connected here
System Expansion (Edge Connector)
System Expansion (Pen Header) Additional option for connecting/accessing the expansion bus
Audio Output: 1.5Vp-p Tape Load (EAR): 500mVp-p Tape Dump (MIC): 90mVp-p Video Output: Dedicated HDMI board (Pico9918)
Tape & Audio On BIT90 these are combined in a DE9 plug along with composite video
Keyboard Column Inputs
These expansion bus pins aren't connected anywhere else at the moment EXTVE (pin 32) EXTV (pin 33) I will pass any unconnected pins through to the extra 2x30 pin header in case they are needed in future. ~{BUSRQ} wasn't connected to Z80, just pulled high, so I have connected it through. ~{INT} wasn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
Keyboard Matrix

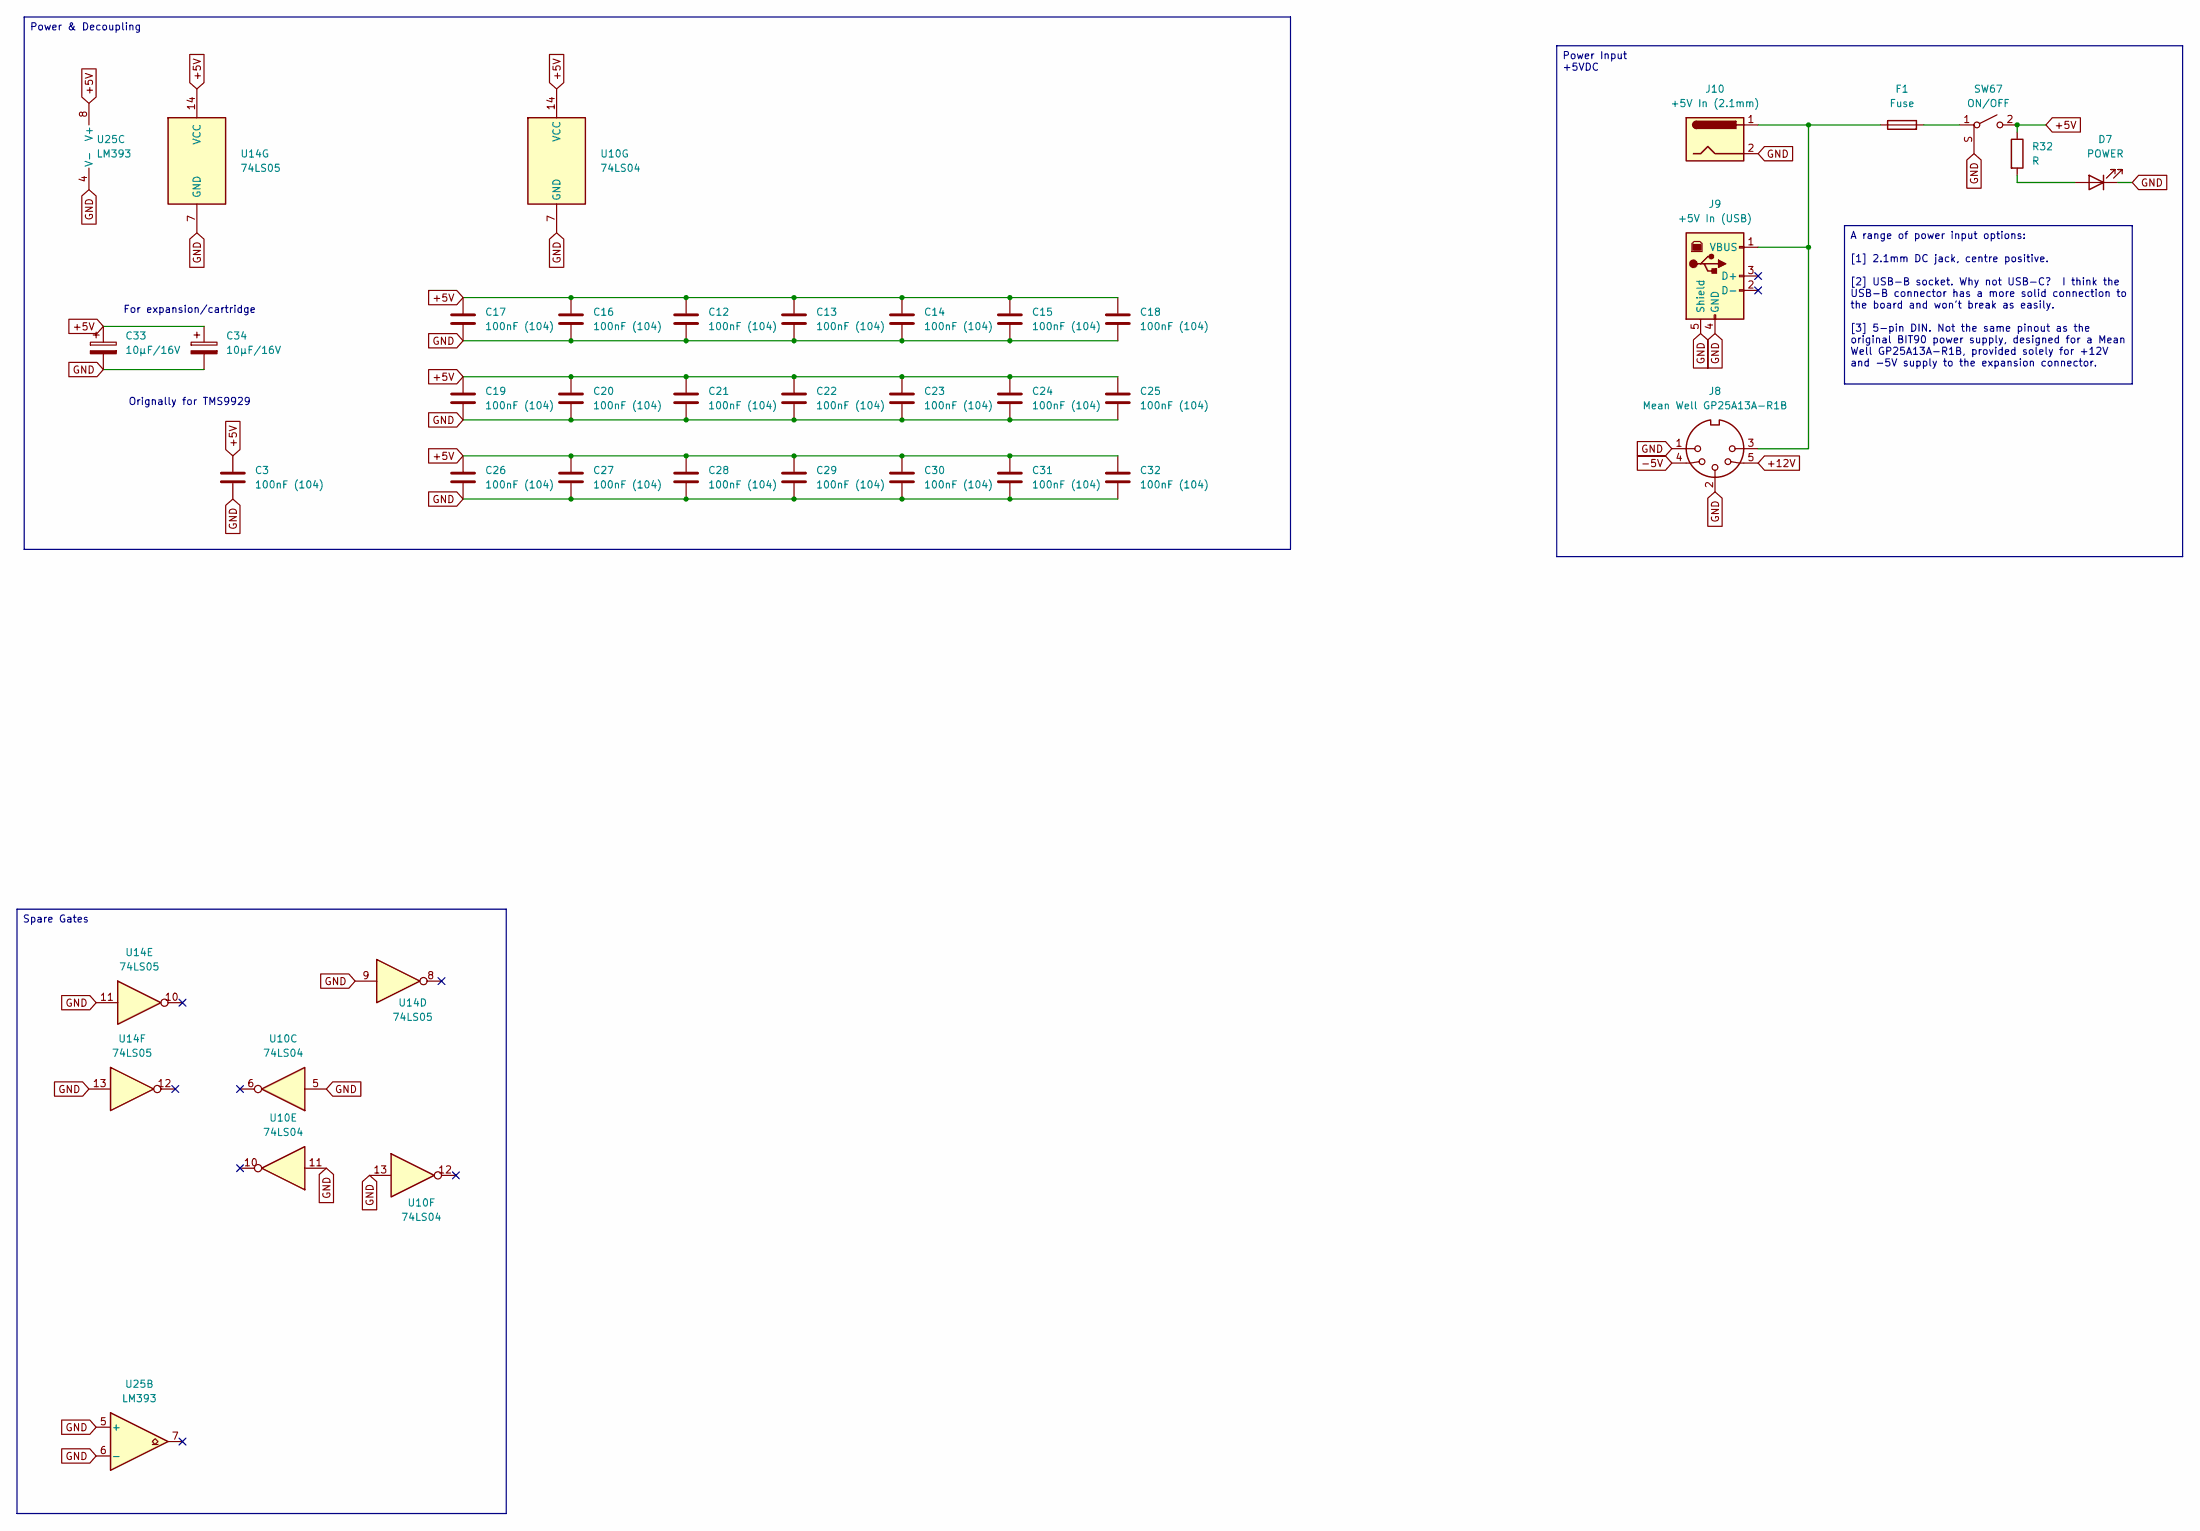
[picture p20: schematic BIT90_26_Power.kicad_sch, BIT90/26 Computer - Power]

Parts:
C3, C12, C13, C14, C15, C16, C17, C18, C19, C20, C21, C22, C23, C24, C25, C26, C27, C28, C29, C30, C31, C32: 100nF (104); C_Disc_D3.4mm_W2.1mm_P2.50mm
C33, C34: 10µF/16V; CP_Radial_D6.3mm_P2.50mm
D7: POWER; LED_D5.0mm
F1: Fuse; Fuseholder_Clip-5x20mm_Littelfuse_111_Inline_P20.00x5.00mm_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
J8: Mean Well GP25A13A-R1B; SDF80J
J9: +5V In (USB); USB_B_Lumberg_2411_02_Horizontal
J10: +5V In (2.1mm); BarrelJack_Horizontal
R32: R; R_Axial_DIN0207_L6.3mm_D2.5mm_P7.62mm_Horizontal
SW67: ON/OFF; SW_400MSP1R6BLKM6QE
U10: 74LS04; DIP-14_W7.62mm
U14: 74LS05; DIP-14_W7.62mm
U25: LM393; DIP-8_W7.62mm

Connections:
+5V: C3.1, C12.1, C13.1, C14.1, C15.1, C16.1, C17.1, C18.1, C19.1, C20.1, C21.1, C22.1, C23.1, C24.1, C25.1, C26.1, C27.1, C28.1, C29.1, C30.1, C31.1, C32.1, C33.1, C34.1, R32.1, SW67.2 (B), U10.14 (VCC), U14.14 (VCC), U25.8 (V+); also elsewhere on the board
+12V: J8.5; also elsewhere on the board
-5V: J8.4; also elsewhere on the board
GND: C3.2, C12.2, C13.2, C14.2, C15.2, C16.2, C17.2, C18.2, C19.2, C20.2, C21.2, C22.2, C23.2, C24.2, C25.2, C26.2, C27.2, C28.2, C29.2, C30.2, C31.2, C32.2, C33.2, C34.2, D7.1 (K), J8.1, J8.2, J9.4 (GND), J9.5 (Shield), J10.2, SW67.S (SPT), U10.5, U10.7 (GND), U10.11, U10.13, U14.7 (GND), U14.9, U14.11, U14.13, U25.4 (V-), U25.5 (+), U25.6 (-); also elsewhere on the board
unnamed: D7.2 (A), R32.2
unnamed: F1.1, J8.3, J9.1 (VBUS), J10.1
unnamed: F1.2, SW67.1 (A)

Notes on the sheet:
Orignally for TMS9929
For expansion/cartridge
Spare Gates
A range of power input options: [1] 2.1mm DC jack, centre positive. [2] USB-B socket. Why not USB-C? I think the USB-B connector has a more solid connection to the board and won't break as easily. [3] 5-pin DIN. Not the same pinout as the original BIT90 power supply, designed for a Mean Well GP25A1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
Power & Decoupling
Power Input +5VDC

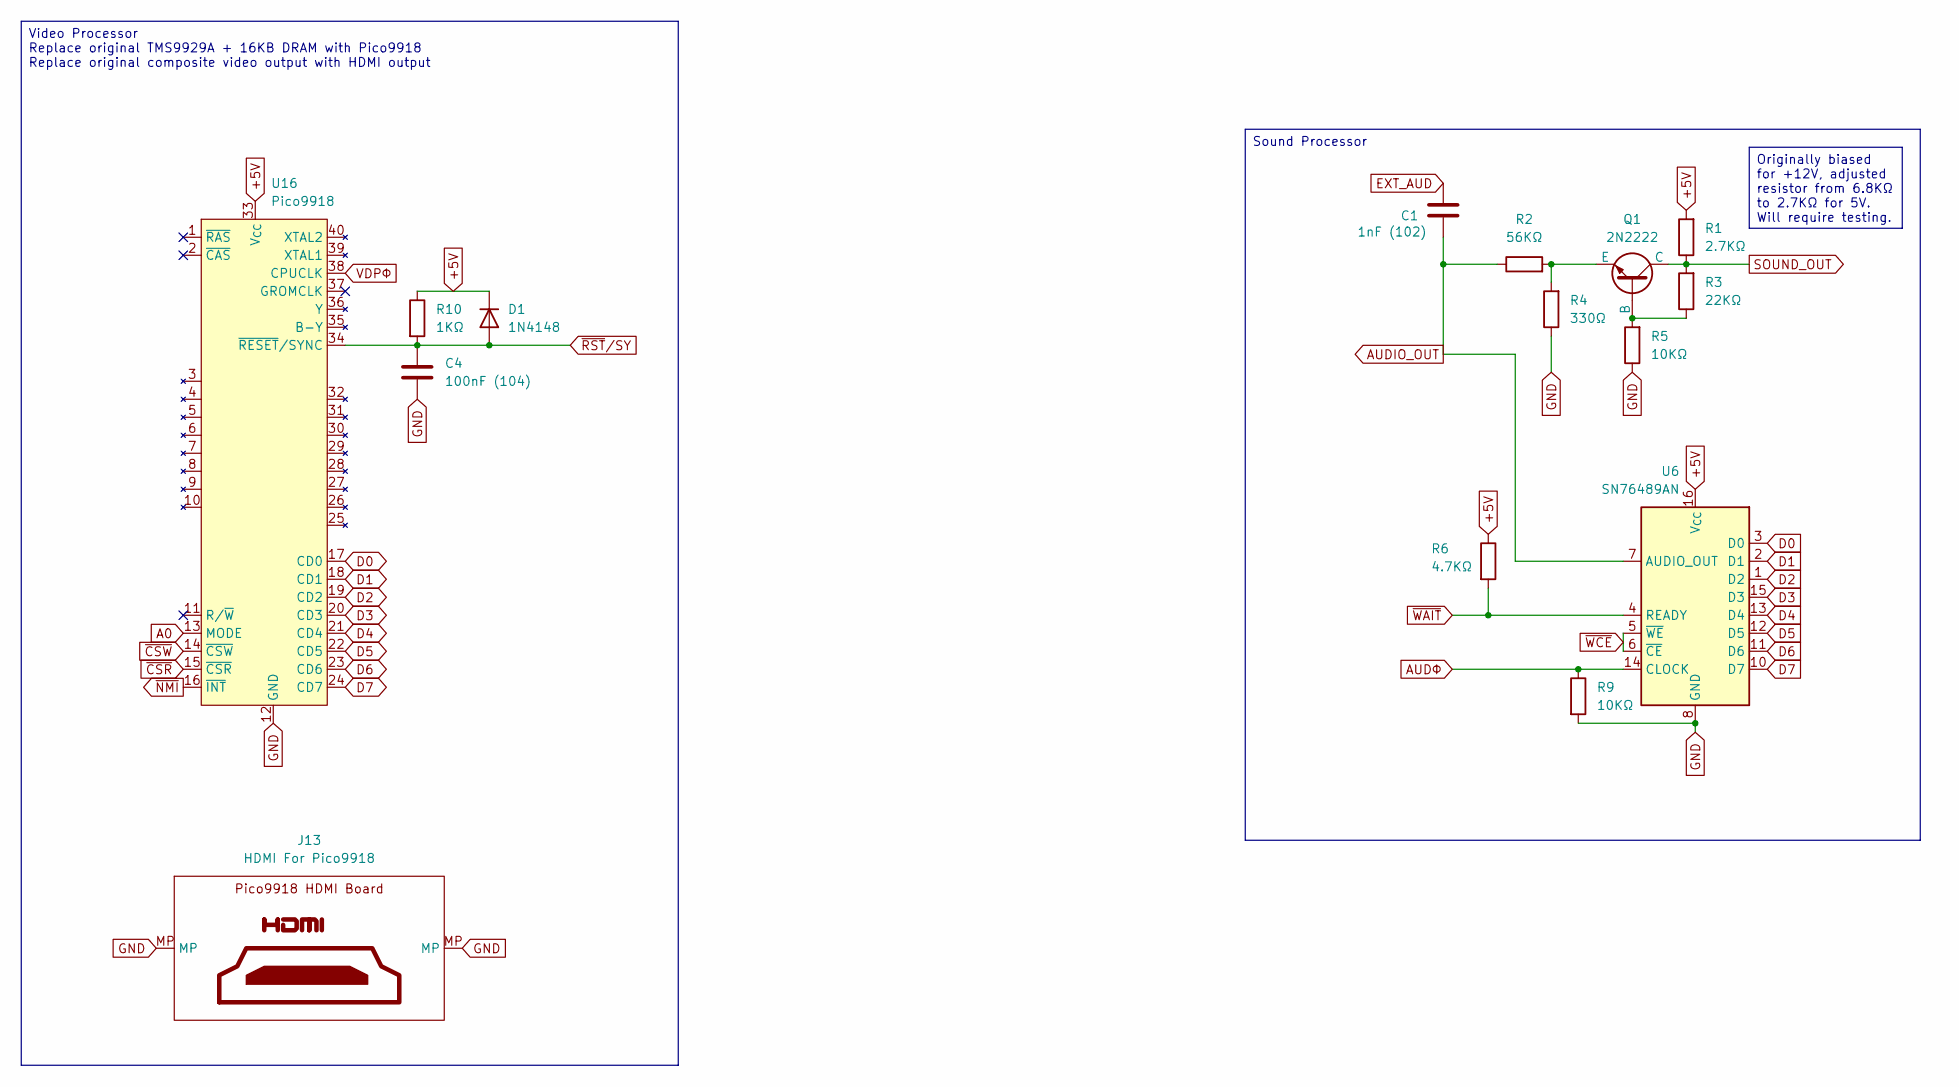
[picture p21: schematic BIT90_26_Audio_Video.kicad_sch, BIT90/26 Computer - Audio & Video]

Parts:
C1: 1nF (102); C_Disc_D3.4mm_W2.1mm_P2.50mm
C4: 100nF (104); C_Disc_D3.4mm_W2.1mm_P2.50mm
D1: 1N4148; D_DO-35_SOD27_P7.62mm_Horizontal
J13: HDMI For Pico9918; Pico9918_HDMI_Board
Q1: 2N2222; TO-92_Inline_Wide
R1: 2.7KΩ; R_Axial_DIN0207_L6.3mm_D2.5mm_P7.62mm_Horizontal
R2: 56KΩ; R_Axial_DIN0207_L6.3mm_D2.5mm_P7.62mm_Horizontal
R3: 22KΩ; R_Axial_DIN0207_L6.3mm_D2.5mm_P7.62mm_Horizontal
R4: 330Ω; R_Axial_DIN0207_L6.3mm_D2.5mm_P7.62mm_Horizontal
R5, R9: 10KΩ; R_Axial_DIN0207_L6.3mm_D2.5mm_P7.62mm_Horizontal
R6: 4.7KΩ; R_Axial_DIN0207_L6.3mm_D2.5mm_P7.62mm_Horizontal
R10: 1KΩ; R_Axial_DIN0207_L6.3mm_D2.5mm_P7.62mm_Horizontal
U6: SN76489AN; DIP-16_W7.62mm
U16: Pico9918; DIP-40_W15.24mm_Socket

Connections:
+5V: D1.1 (K), R1.2, R6.1, R10.1, U6.16 (V_{CC}), U16.33 (V_{CC}); also elsewhere on the board
A0: U16.13 (MODE); also elsewhere on the board
AUDIO_OUT: C1.2, R2.1, U6.7 (AUDIO_OUT); also elsewhere on the board
AUDΦ: R9.1, U6.14 (CLOCK); also elsewhere on the board
D0: U6.3 (D0), U16.17 (CD0); also elsewhere on the board
D1: U6.2 (D1), U16.18 (CD1); also elsewhere on the board
D2: U6.1 (D2), U16.19 (CD2); also elsewhere on the board
D3: U6.15 (D3), U16.20 (CD3); also elsewhere on the board
D4: U6.13 (D4), U16.21 (CD4); also elsewhere on the board
D5: U6.12 (D5), U16.22 (CD5); also elsewhere on the board
D6: U6.11 (D6), U16.23 (CD6); also elsewhere on the board
D7: U6.10 (D7), U16.24 (CD7); also elsewhere on the board
EXT_AUD: C1.1; also elsewhere on the board
GND: C4.2, J13.MP, R4.1, R5.1, R9.2, U6.8 (GND), U16.12 (GND); also elsewhere on the board
unnamed: Q1.2 (B), R3.1, R5.2
unnamed: Q1.3 (E), R2.2, R4.2
SOUND_OUT: Q1.1 (C), R1.1, R3.2; also elsewhere on the board
VDPΦ: U16.38 (CPUCLK); also elsewhere on the board
~CSR: U16.15 (~CSR); also elsewhere on the board
~CSW: U16.14 (~CSW); also elsewhere on the board
~NMI: U16.16 (~INT); also elsewhere on the board
~RST/SY: C4.1, D1.2 (A), R10.2, U16.34 (~RESET/SYNC); also elsewhere on the board
~WAIT: R6.2, U6.4 (READY); also elsewhere on the board
~WCE: U6.5 (~WE), U6.6 (~CE); also elsewhere on the board

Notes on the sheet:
Video Processor Replace original TMS9929A + 16KB DRAM with Pico9918 Replace original composite video output with HDMI output
Originally biased for +12V, adjusted resistor from 6.8KΩ to 2.7KΩ for 5V. Will require testing.
Sound Processor

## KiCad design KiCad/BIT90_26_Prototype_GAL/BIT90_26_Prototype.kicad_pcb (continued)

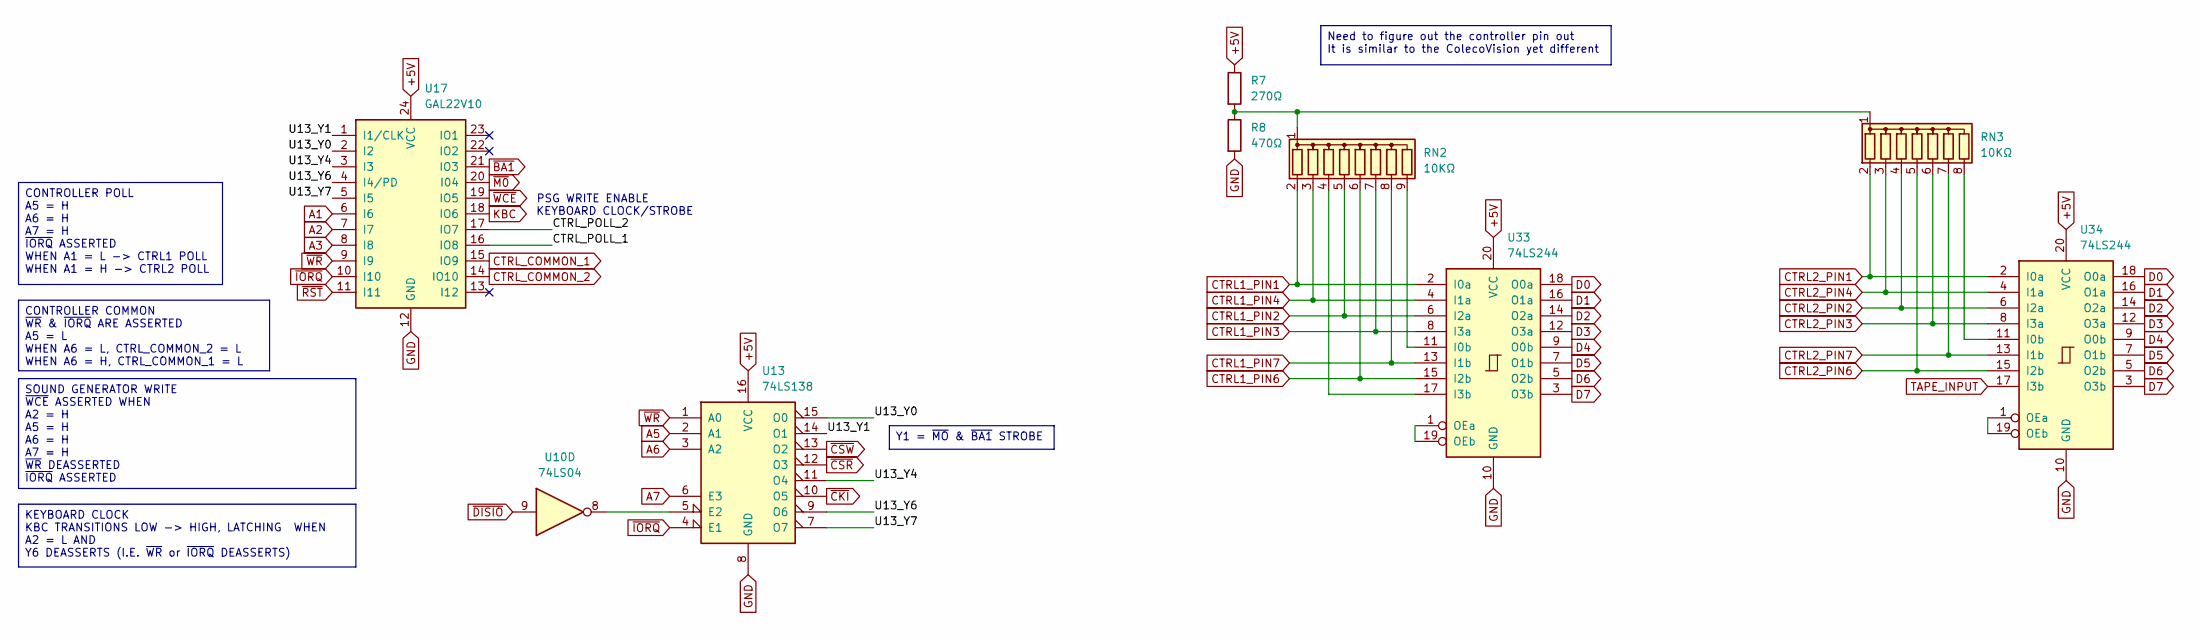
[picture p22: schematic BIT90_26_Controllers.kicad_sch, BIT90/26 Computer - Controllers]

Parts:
R7: 270Ω; R_Axial_DIN0207_L6.3mm_D2.5mm_P7.62mm_Horizontal
R8: 470Ω; R_Axial_DIN0207_L6.3mm_D2.5mm_P7.62mm_Horizontal
RN2: 10KΩ; R_Array_SIP9
RN3: 10KΩ; R_Array_SIP8
U10: 74LS04; DIP-14_W7.62mm
U13: 74LS138; DIP-16_W7.62mm
U17: GAL22V10; DIP-24_W7.62mm
U33, U34: 74LS244; DIP-20_W7.62mm

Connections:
+5V: R7.1, U13.16 (VCC), U17.24 (VCC), U33.20 (VCC), U34.20 (VCC); also elsewhere on the board
/Controllers/CTRL_POLL_1: U17.16 (IO8)
/Controllers/CTRL_POLL_2: U17.17 (IO7)
/Controllers/U13_Y0: U13.15 (O0), U17.2 (I2)
/Controllers/U13_Y1: U13.14 (O1), U17.1 (I1/CLK)
/Controllers/U13_Y4: U13.11 (O4), U17.3 (I3)
/Controllers/U13_Y6: U13.9 (O6), U17.4 (I4/PD)
/Controllers/U13_Y7: U13.7 (O7), U17.5 (I5)
A1: U17.6 (I6); also elsewhere on the board
A2: U17.7 (I7); also elsewhere on the board
A3: U17.8 (I8); also elsewhere on the board
A5: U13.2 (A1); also elsewhere on the board
A6: U13.3 (A2); also elsewhere on the board
A7: U13.6 (E3); also elsewhere on the board
CTRL1_PIN1: RN2.2 (R1), U33.2 (I0a); also elsewhere on the board
CTRL1_PIN2: RN2.5 (R4), U33.6 (I2a); also elsewhere on the board
CTRL1_PIN3: RN2.7 (R6), U33.8 (I3a); also elsewhere on the board
CTRL1_PIN4: RN2.3 (R2), U33.4 (I1a); also elsewhere on the board
CTRL1_PIN6: RN2.6 (R5), U33.15 (I2b); also elsewhere on the board
CTRL1_PIN7: RN2.8 (R7), U33.13 (I1b); also elsewhere on the board
CTRL2_PIN1: RN3.2 (R1), U34.2 (I0a); also elsewhere on the board
CTRL2_PIN2: RN3.4 (R3), U34.6 (I2a); also elsewhere on the board
CTRL2_PIN3: RN3.6 (R5), U34.8 (I3a); also elsewhere on the board
CTRL2_PIN4: RN3.3 (R2), U34.4 (I1a); also elsewhere on the board
CTRL2_PIN6: RN3.5 (R4), U34.15 (I2b); also elsewhere on the board
CTRL2_PIN7: RN3.7 (R6), U34.13 (I1b); also elsewhere on the board
CTRL_COMMON_1: U17.15 (IO9); also elsewhere on the board
CTRL_COMMON_2: U17.14 (IO10); also elsewhere on the board
D0: U33.18 (O0a), U34.18 (O0a); also elsewhere on the board
D1: U33.16 (O1a), U34.16 (O1a); also elsewhere on the board
D2: U33.14 (O2a), U34.14 (O2a); also elsewhere on the board
D3: U33.12 (O3a), U34.12 (O3a); also elsewhere on the board
D4: U33.9 (O0b), U34.9 (O0b); also elsewhere on the board
D5: U33.7 (O1b), U34.7 (O1b); also elsewhere on the board
D6: U33.5 (O2b), U34.5 (O2b); also elsewhere on the board
D7: U33.3 (O3b), U34.3 (O3b); also elsewhere on the board
GND: R8.2, U13.8 (GND), U17.12 (GND), U33.10 (GND), U34.10 (GND); also elsewhere on the board
KBC: U17.18 (IO6); also elsewhere on the board
unnamed: RN2.4 (R3), U33.17 (I3b)
unnamed: RN2.9 (R8), U33.11 (I0b)
unnamed: R7.2, R8.1, RN2.1 (common), RN3.1 (common)
unnamed: RN3.8 (R7), U34.11 (I0b)
unnamed: U10.8, U13.5 (E2)
unnamed: U33.1 (OEa), U33.19 (OEb)
unnamed: U34.1 (OEa), U34.19 (OEb)
TAPE_INPUT: U34.17 (I3b); also elsewhere on the board
~BA1: U17.21 (IO3); also elsewhere on the board
~CKI: U13.10 (O5); also elsewhere on the board
~CSR: U13.12 (O3); also elsewhere on the board
~CSW: U13.13 (O2); also elsewhere on the board
~DISIO: U10.9; also elsewhere on the board
~IORQ: U13.4 (E1), U17.10 (I10); also elsewhere on the board
~M0: U17.20 (I04); also elsewhere on the board
~RST: U17.11 (I11); also elsewhere on the board
~WCE: U17.19 (IO5); also elsewhere on the board
~WR: U13.1 (A0), U17.9 (I9); also elsewhere on the board

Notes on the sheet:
PSG WRITE ENABLE
KEYBOARD CLOCK/STROBE
Need to figure out the controller pin out It is similar to the ColecoVision yet different
KEYBOARD CLOCK KBC TRANSITIONS LOW -> HIGH, LATCHING WHEN A2 = L AND Y6 DEASSERTS (I.E. ~{WR} or ~{IORQ} DEASSERTS)
CONTROLLER POLL A5 = H A6 = H A7 = H ~{IORQ} ASSERTED WHEN A1 = L -> CTRL1 POLL WHEN A1 = H -> CTRL2 POLL
CONTROLLER COMMON ~{WR} & ~{IORQ} ARE ASSERTED A5 = L WHEN A6 = L, CTRL_COMMON_2 = L WHEN A6 = H, CTRL_COMMON_1 = L
Y1 = ~{MO} & ~{BA1} STROBE
SOUND GENERATOR WRITE ~{WCE} ASSERTED WHEN A2 = H A5 = H A6 = H A7 = H ~{WR} DEASSERTED ~{IORQ} ASSERTED

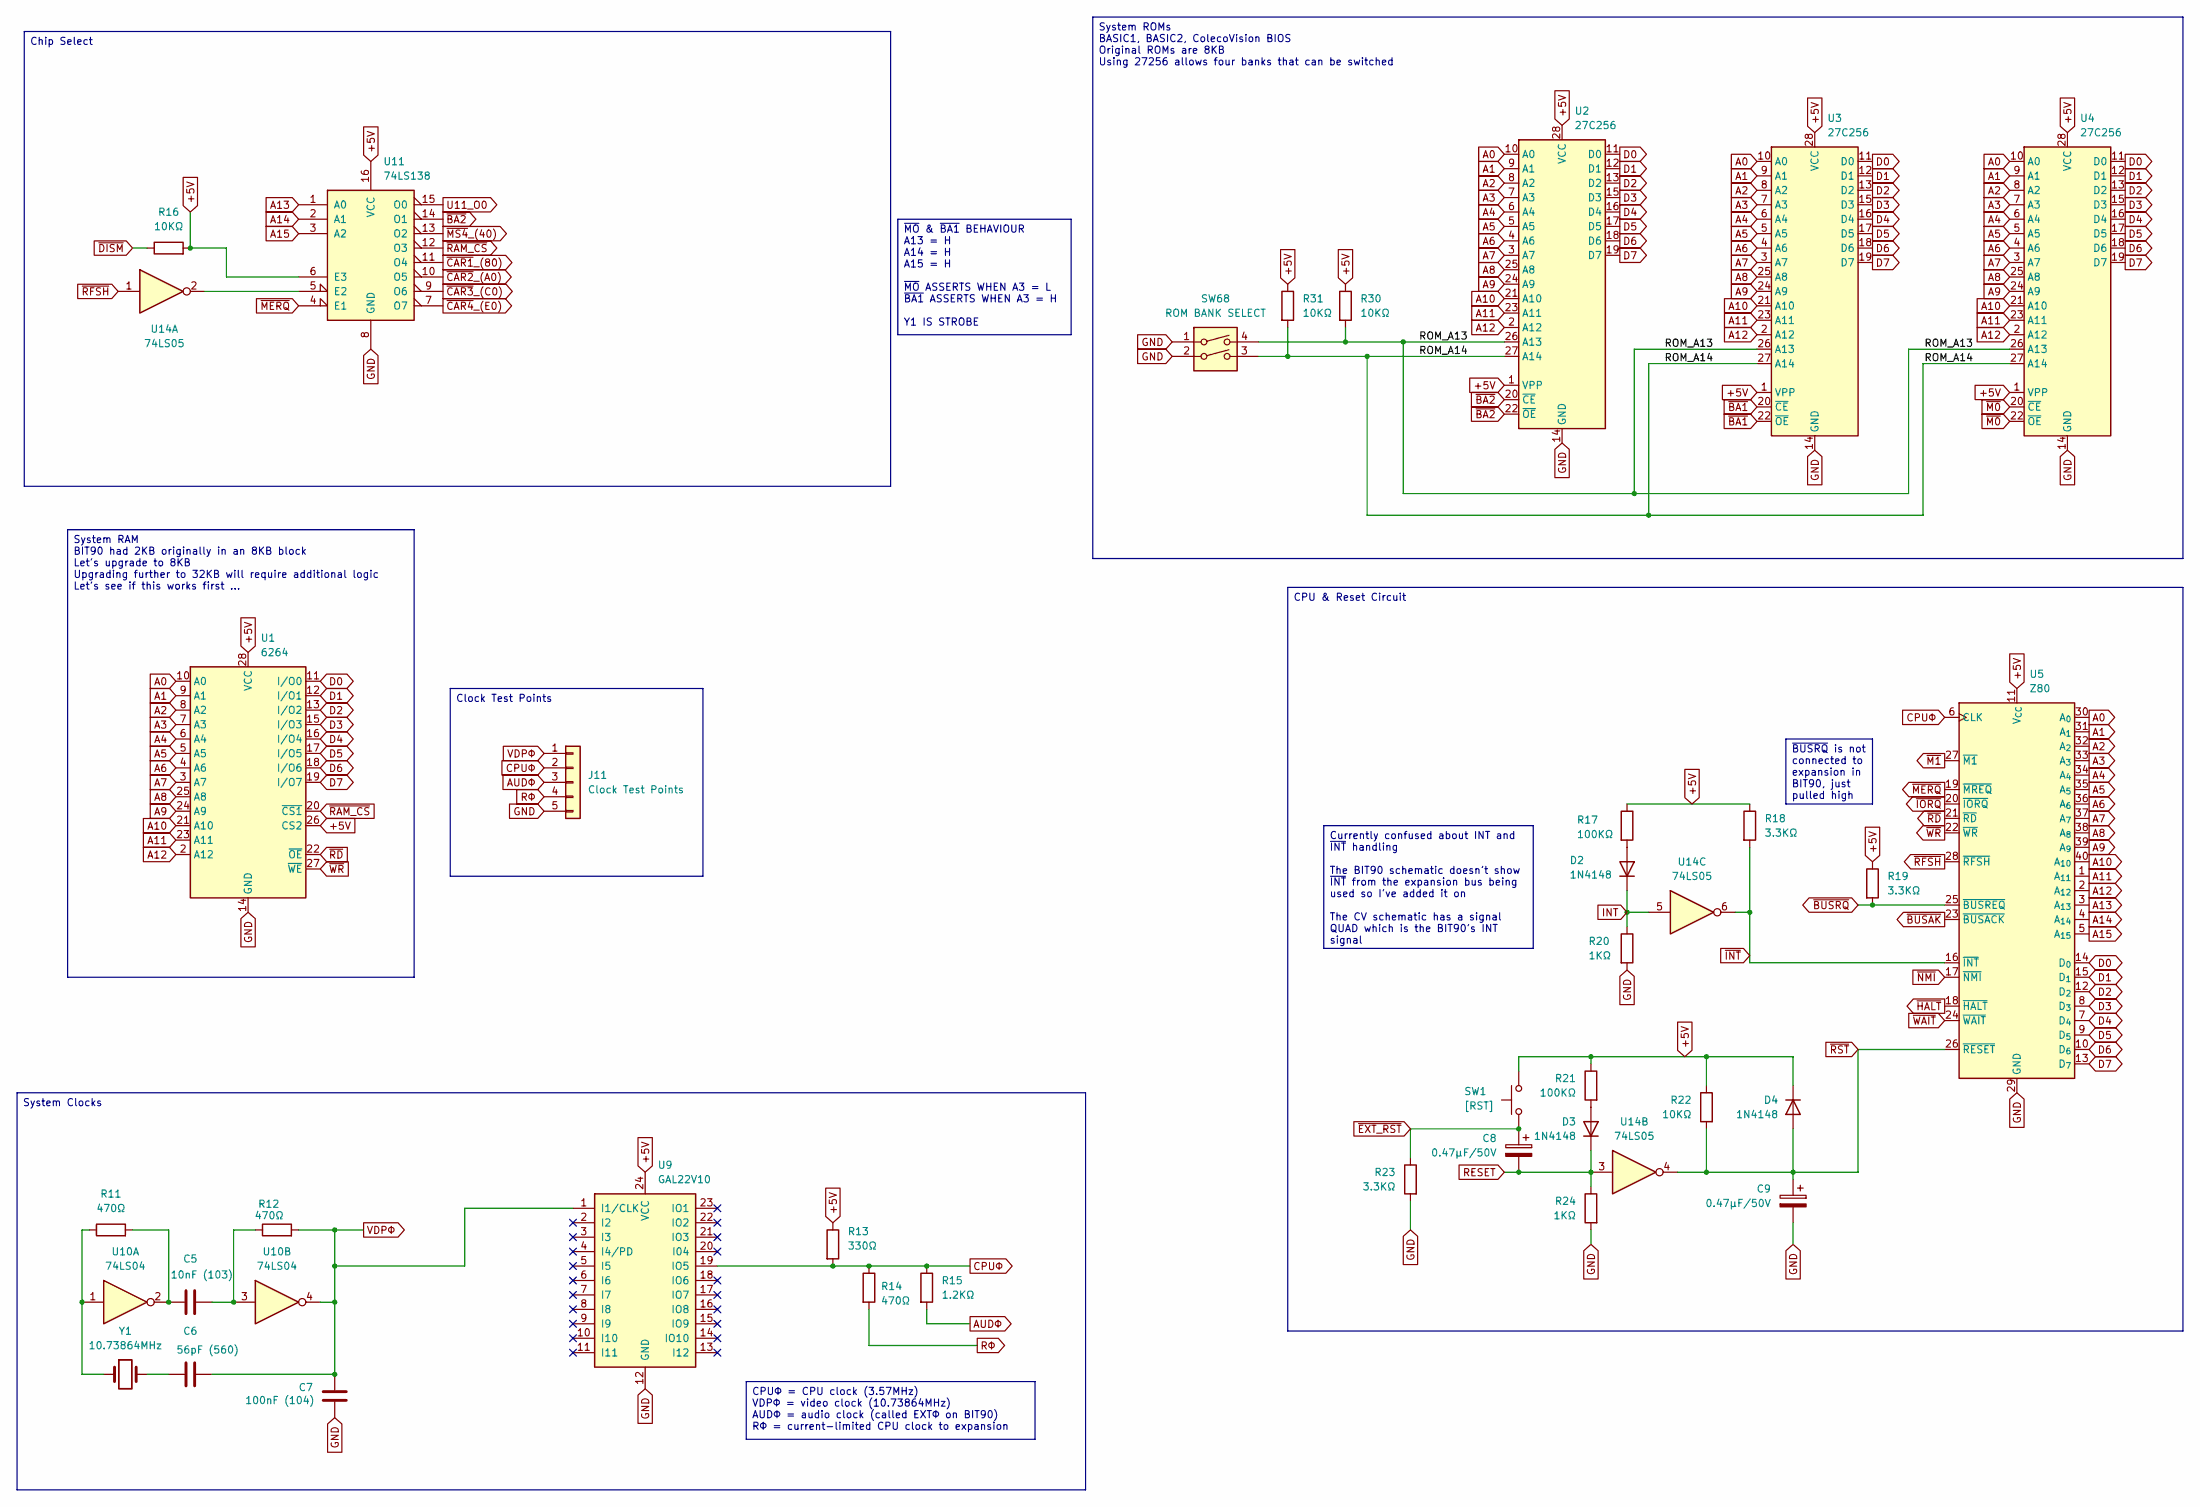
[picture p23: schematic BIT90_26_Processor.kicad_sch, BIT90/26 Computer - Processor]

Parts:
C5: 10nF (103); C_Disc_D3.4mm_W2.1mm_P2.50mm
C6: 56pF (560); C_Disc_D3.4mm_W2.1mm_P2.50mm
C7: 100nF (104); C_Disc_D3.4mm_W2.1mm_P2.50mm
C8, C9: 0.47µF/50V; CP_Radial_D6.3mm_P2.50mm
D2, D3, D4: 1N4148; D_DO-35_SOD27_P7.62mm_Horizontal
J11: Clock Test Points; PinHeader_1x05_P2.54mm_Vertical
R11, R12, R14: 470Ω; R_Axial_DIN0207_L6.3mm_D2.5mm_P7.62mm_Horizontal
R13: 330Ω; R_Axial_DIN0207_L6.3mm_D2.5mm_P7.62mm_Horizontal
R15: 1.2KΩ; R_Axial_DIN0207_L6.3mm_D2.5mm_P7.62mm_Horizontal
R16, R22, R30, R31: 10KΩ; R_Axial_DIN0207_L6.3mm_D2.5mm_P7.62mm_Horizontal
R17, R21: 100KΩ; R_Axial_DIN0207_L6.3mm_D2.5mm_P7.62mm_Horizontal
R18, R19, R23: 3.3KΩ; R_Axial_DIN0207_L6.3mm_D2.5mm_P7.62mm_Horizontal
R20, R24: 1KΩ; R_Axial_DIN0207_L6.3mm_D2.5mm_P7.62mm_Horizontal
SW1: [RST]; SW_Gateron_LowProfile_THT
SW68: ROM BANK SELECT; SW_DIP_SPSTx02_Slide_9.78x7.26mm_W7.62mm_P2.54mm
U1: 6264; DIP-28_W15.24mm
U2, U3, U4: 27C256; DIP-28_W15.24mm
U5: Z80; DIP-40_W15.24mm
U9: GAL22V10; DIP-24_W7.62mm
U10: 74LS04; DIP-14_W7.62mm
U11: 74LS138; DIP-16_W7.62mm
U14: 74LS05; DIP-14_W7.62mm
Y1: 10.73864MHz; Crystal_HC49-U_Vertical

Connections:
+5V: D4.1 (K), R13.1, R16.2, R17.1, R18.1, R19.1, R21.1, R22.1, R30.1, R31.1, SW1.1, U1.26 (CS2), U1.28 (VCC), U2.1 (VPP), U2.28 (VCC), U3.1 (VPP), U3.28 (VCC), U4.1 (VPP), U4.28 (VCC), U5.11 (V_{CC}), U9.24 (VCC), U11.6 (E3), U11.16 (VCC); also elsewhere on the board
/Processor/ROM_A13: R30.2, SW68.4, U2.26 (A13), U3.26 (A13), U4.26 (A13)
/Processor/ROM_A14: R31.2, SW68.3, U2.27 (A14), U3.27 (A14), U4.27 (A14)
A0: U1.10 (A0), U2.10 (A0), U3.10 (A0), U4.10 (A0), U5.30 (A_{0}); also elsewhere on the board
A1: U1.9 (A1), U2.9 (A1), U3.9 (A1), U4.9 (A1), U5.31 (A_{1}); also elsewhere on the board
A2: U1.8 (A2), U2.8 (A2), U3.8 (A2), U4.8 (A2), U5.32 (A_{2}); also elsewhere on the board
A3: U1.7 (A3), U2.7 (A3), U3.7 (A3), U4.7 (A3), U5.33 (A_{3}); also elsewhere on the board
A4: U1.6 (A4), U2.6 (A4), U3.6 (A4), U4.6 (A4), U5.34 (A_{4}); also elsewhere on the board
A5: U1.5 (A5), U2.5 (A5), U3.5 (A5), U4.5 (A5), U5.35 (A_{5}); also elsewhere on the board
A6: U1.4 (A6), U2.4 (A6), U3.4 (A6), U4.4 (A6), U5.36 (A_{6}); also elsewhere on the board
A7: U1.3 (A7), U2.3 (A7), U3.3 (A7), U4.3 (A7), U5.37 (A_{7}); also elsewhere on the board
A8: U1.25 (A8), U2.25 (A8), U3.25 (A8), U4.25 (A8), U5.38 (A_{8}); also elsewhere on the board
A9: U1.24 (A9), U2.24 (A9), U3.24 (A9), U4.24 (A9), U5.39 (A_{9}); also elsewhere on the board
A10: U1.21 (A10), U2.21 (A10), U3.21 (A10), U4.21 (A10), U5.40 (A_{10}); also elsewhere on the board
A11: U1.23 (A11), U2.23 (A11), U3.23 (A11), U4.23 (A11), U5.1 (A_{11}); also elsewhere on the board
A12: U1.2 (A12), U2.2 (A12), U3.2 (A12), U4.2 (A12), U5.2 (A_{12}); also elsewhere on the board
A13: U5.3 (A_{13}), U11.1 (A0); also elsewhere on the board
A14: U5.4 (A_{14}), U11.2 (A1); also elsewhere on the board
A15: U5.5 (A_{15}), U11.3 (A2); also elsewhere on the board
AUDΦ: J11.3, R15.2; also elsewhere on the board
CPUΦ: J11.2, R13.2, R14.1, R15.1, U5.6 (CLK), U9.19 (IO5); also elsewhere on the board
D0: U1.11 (I/O0), U2.11 (D0), U3.11 (D0), U4.11 (D0), U5.14 (D_{0}); also elsewhere on the board
D1: U1.12 (I/O1), U2.12 (D1), U3.12 (D1), U4.12 (D1), U5.15 (D_{1}); also elsewhere on the board
D2: U1.13 (I/O2), U2.13 (D2), U3.13 (D2), U4.13 (D2), U5.12 (D_{2}); also elsewhere on the board
D3: U1.15 (I/O3), U2.15 (D3), U3.15 (D3), U4.15 (D3), U5.8 (D_{3}); also elsewhere on the board
D4: U1.16 (I/O4), U2.16 (D4), U3.16 (D4), U4.16 (D4), U5.7 (D_{4}); also elsewhere on the board
D5: U1.17 (I/O5), U2.17 (D5), U3.17 (D5), U4.17 (D5), U5.9 (D_{5}); also elsewhere on the board
D6: U1.18 (I/O6), U2.18 (D6), U3.18 (D6), U4.18 (D6), U5.10 (D_{6}); also elsewhere on the board
D7: U1.19 (I/O7), U2.19 (D7), U3.19 (D7), U4.19 (D7), U5.13 (D_{7}); also elsewhere on the board
GND: C7.1, C9.2, J11.5, R20.2, R23.2, R24.2, SW68.1, SW68.2, U1.14 (GND), U2.14 (GND), U3.14 (GND), U4.14 (GND), U5.29 (GND), U9.12 (GND), U11.8 (GND); also elsewhere on the board
INT: D2.1 (K), R20.1, U14.5; also elsewhere on the board
unnamed: C5.1, R11.2, U10.2
unnamed: C5.2, R12.1, U10.3
unnamed: C6.1, Y1.2
unnamed: D2.2 (A), R17.2
unnamed: D3.2 (A), R21.2
unnamed: R11.1, U10.1, Y1.1
unnamed: U11.5 (E2), U14.2
RESET: C8.2, D3.1 (K), R24.1, U14.3; also elsewhere on the board
RΦ: J11.4, R14.2; also elsewhere on the board
U11_O0: U11.15 (O0)
VDPΦ: C6.2, C7.2, J11.1, R12.2, U9.1 (I1/CLK), U10.4; also elsewhere on the board
~BA1: U3.20 (~CE), U3.22 (~OE); also elsewhere on the board
~BA2: U2.20 (~CE), U2.22 (~OE), U11.14 (O1)
~BUSAK: U5.23 (~BUSACK); also elsewhere on the board
~BUSRQ: R19.2, U5.25 (~BUSREQ); also elsewhere on the board
~CAR1_(80): U11.11 (O4); also elsewhere on the board
~CAR2_(A0): U11.10 (O5); also elsewhere on the board
~CAR3_(C0): U11.9 (O6); also elsewhere on the board
~CAR4_(E0): U11.7 (O7); also elsewhere on the board
~DISM: R16.1; also elsewhere on the board
~EXT_RST: C8.1, R23.1, SW1.2; also elsewhere on the board
~HALT: U5.18 (~HALT); also elsewhere on the board
~INT: R18.2, U5.16 (~INT), U14.6; also elsewhere on the board
~IORQ: U5.20 (~IORQ); also elsewhere on the board
~M0: U4.20 (~CE), U4.22 (~OE); also elsewhere on the board
~M1: U5.27 (~M1); also elsewhere on the board
~MERQ: U5.19 (~MREQ), U11.4 (E1); also elsewhere on the board
~MS4_(40): U11.13 (O2); also elsewhere on the board
~NMI: U5.17 (~NMI); also elsewhere on the board
~RAM_CS: U1.20 (~CS1), U11.12 (O3)
~RD: U1.22 (~OE), U5.21 (~RD); also elsewhere on the board
~RFSH: U5.28 (~RFSH), U14.1; also elsewhere on the board
~RST: C9.1, D4.2 (A), R22.2, U5.26 (~RESET), U14.4; also elsewhere on the board
~WAIT: U5.24 (~WAIT); also elsewhere on the board
~WR: U1.27 (~WE), U5.22 (~WR); also elsewhere on the board

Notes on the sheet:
CPU & Reset Circuit
~{BUSRQ} is not connected to expansion in BIT90, just pulled high
System Clocks
Clock Test Points
System ROMs BASIC1, BASIC2, ColecoVision BIOS Original ROMs are 8KB Using 27256 allows four banks that can be switched
Currently confused about INT and ~{INT} handling The BIT90 schematic doesn't show ~{INT} from the expansion bus being used so I've added it on The CV schematic has a signal QUAD which is the BIT90's INT signal
Chip Select
~{MO} & ~{BA1} BEHAVIOUR A13 = H A14 = H A15 = H ~{MO} ASSERTS WHEN A3 = L ~{BA1} ASSERTS WHEN A3 = H Y1 IS STROBE
CPUΦ = CPU clock (3.57MHz) VDPΦ = video clock (10.73864MHz) AUDΦ = audio clock (called EXTΦ on BIT90) RΦ = current-limited CPU clock to expansion
System RAM BIT90 had 2KB originally in an 8KB block Let's upgrade to 8KB Upgrading further to 32KB will require additional logic Let's see if this works first ...

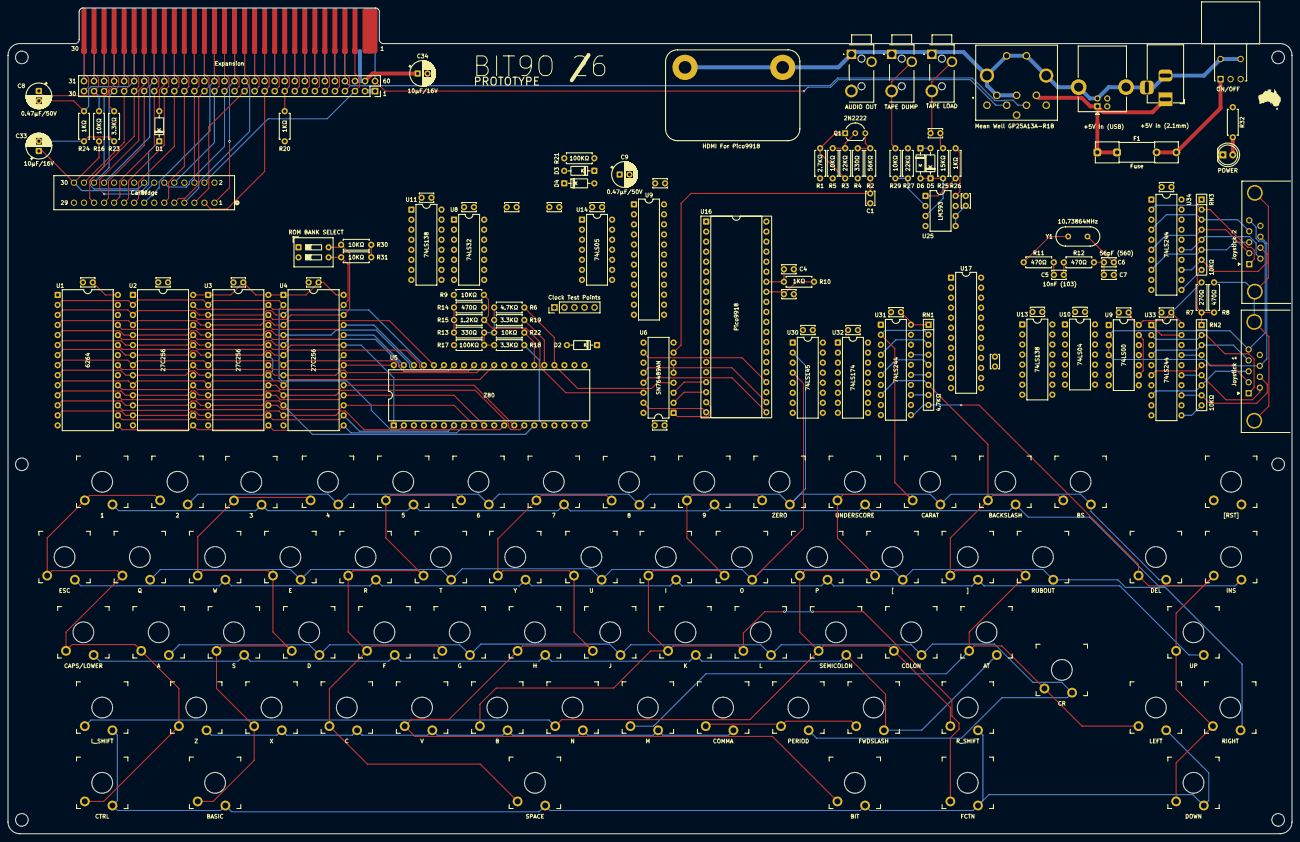
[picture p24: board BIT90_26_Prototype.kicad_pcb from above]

Board: 2 copper layers, 325.0 x 209.0 mm, 184 parts (0 on the bottom side), 141 nets.

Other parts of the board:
U8: 74LS32; DIP-14_W7.62mm
U9#2: 74LS00; DIP-14_W7.62mm

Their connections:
+5V: U8.14 (VCC), U9#2.14 (VCC); also elsewhere on the board
A2: U9#2.12; also elsewhere on the board
CPUΦ: U8.6; also elsewhere on the board
CTRL_COMMON_1: U9#2.3, U9#2.4; also elsewhere on the board
CTRL_COMMON_2: U9#2.2, U9#2.6; also elsewhere on the board
GND: U8.1, U8.2, U8.7 (GND), U9#2.7 (GND); also elsewhere on the board
KBC: U9#2.8; also elsewhere on the board
unnamed: U9#2.9, U9#2.13
unnamed: U8.9, U8.12
~BA1: U8.11; also elsewhere on the board
~M0: U8.8; also elsewhere on the board
~WCE: U9#2.11; also elsewhere on the board

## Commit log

2026-06-03 Initial commit
    Very early work-in-progress on recreating original schematic
    [BIT90_Interfaces.kicad_sch, BIT90_Keyboard.kicad_sch, BIT90_Original.kicad_pcb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]
2026-06-03 Added "Processor" Sheet 6-1
    [BIT90_Interfaces.kicad_sch, BIT90_Keyboard.kicad_sch, BIT90_Original.kicad_sch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]
2026-06-03 Completed keyboard schematic
    [BIT90_Interfaces.kicad_sch, BIT90_Keyboard.kicad_sch, BIT90_Processor.kicad_sch]
2026-06-03 Added "Video Control" schematic
    [BIT90_Keyboard.kicad_sch, BIT90_Original.kicad_sch, BIT90_Power.kicad_sch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]
2026-06-03 Added "Joystick, Audio, Tape Out" schematic
    [BIT90_Interfaces.kicad_sch, BIT90_Joystick_Audio_TapeOut.kicad_sch, BIT90_Keyboard.kicad_sch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]
2026-06-03 Minor schematic corrections
    [BIT90_Interfaces.kicad_sch, BIT90_Joystick_Audio_TapeOut.kicad_sch, BIT90_Keyboard.kicad_sch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]
2026-06-03 Updated info about ROMs
    From b3rendsh info: there can be 24-pin 2364 masked ROMs, 28-pin 2764 EPROMs or a mixture.
    [BIT90_Processor.kicad_sch]
2026-06-03 Moved redrawn schematic PDFs to own folder
2026-06-03 Completed original schematic redraw
    Well, didn't finish the Video Encoder (PAL) sheet as I'm not going to use any of it in the new design.
    Moved the audio output from that sheet to the Joystick/Audio/Tape out sheet where the sound generator is.
    [BIT90_Interfaces.kicad_sch, BIT90_Joystick_Audio_TapeOut.kicad_sch, BIT90_Keyboard.kicad_sch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]
2026-06-04 Keyboard layout created
    [bit90-keyboard_switch_template.dxf]
2026-06-05 Added useful references
    Just a backup in case original links, sites, Google Drives, disappear ... this is likely vital information that needs to be referenced in 2076!
2026-06-05 Resolving BIT90 schematic errors #1
    The original BIT90 schematic was confusing as the controller/joystick buffer enable pins were wired weirdly. But thanks to motherboard underside photo from Henk & CV schematics, resolved!
    [BIT90_Scraps.kicad_pcb, BIT90_Scraps.kicad_sch]
2026-06-05 Small updates/corrections
    Managed to figure out some more errors/missing info from ColecoVision schematics & Henk's BIT90 motherboard underside photo
    [BIT90_Interfaces.kicad_sch, BIT90_Joystick_Audio_TapeOut.kicad_sch, BIT90_Keyboard.kicad_sch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]
2026-06-05 Resolved audio clock signal
    Marked as EXTΦ on BIT90 schematic, generated via resistor from CPUΦ
    Renamed it as AUDΦ so it's a bit clearer
    [BIT90_Interfaces.kicad_sch, BIT90_Joystick_Audio_TapeOut.kicad_sch, BIT90_Keyboard.kicad_sch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]
2026-06-05 Initial redesign completed
    Most errors are expansion bus signals that aren't connected anywhere else
    [BIT90_26.kicad_sch, BIT90_26_Audio_Video.kicad_sch, BIT90_26_Controllers.kicad_sch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]
2026-06-05 Minor schematic update
    Henk: On my system board the R7 and C14 components are not mounted on the PCB.
    [BIT90_Keyboard.kicad_sch, BIT90_Original.kicad_sch, BIT90_Video_Control.kicad_sch]
2026-06-06 Minor corrections & footprints assigned
    PCB layout started
    [BIT90_26.kicad_sch, BIT90_26_Audio_Video.kicad_sch, BIT90_26_Controllers.kicad_sch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]
2026-06-06 Minor corrections
    [BIT90_Interfaces.kicad_sch, BIT90_Joystick_Audio_TapeOut.kicad_sch, BIT90_Keyboard.kicad_sch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]
2026-06-06 PCB layout started
    [BIT90_26.kicad_pcb, BIT90_26_Controllers.kicad_sch, BIT90_26_Keyboard_Interfaces.kicad_sch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]
2026-06-07 Moved initial design to Prototype folder
    [BIT90_26_Audio_Video.kicad_sch, BIT90_26_Controllers.kicad_sch, BIT90_26_Keyboard_Interfaces.kicad_sch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]
2026-06-07 Added more signal analysis to schematic
    Would be nice to reduce the amount of glue logic
    [BIT90_26_Audio_Video.kicad_sch, BIT90_26_Controllers.kicad_sch, BIT90_26_Keyboard_Interfaces.kicad_sch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]
2026-06-07 Started revised design using GALs
    Removing some glue logic to try to simplify the PCB routing
    Removed 74LS74, 74LS107, 74LS32, 74LS00
    [BIT90_26_Audio_Video.kicad_sch, BIT90_26_Controllers.kicad_sch, BIT90_26_Keyboard_Interfaces.kicad_sch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]
